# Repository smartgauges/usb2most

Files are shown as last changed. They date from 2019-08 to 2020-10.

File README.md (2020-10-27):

# usb2most
USB to MOST adapter to translate audio from a USB([UAC1](https://en.wikipedia.org/wiki/USB#Audio_streaming)) to MOST([Media Oriented Systems Transport](https://en.wikipedia.org/wiki/MOST_Bus)) bus

Interfaces:
- 8 audio channels(16bit/48kHz) over MOST bus
- 2 audio channels(16bit/48kHz) over USB
- 4 CAN for HS/HS" and MS/MS"
- 1 LIN for analogue watch
- 1 UART for CANBUS emulation

[More info](https://www.drive2.ru/l/524415370476389031/)

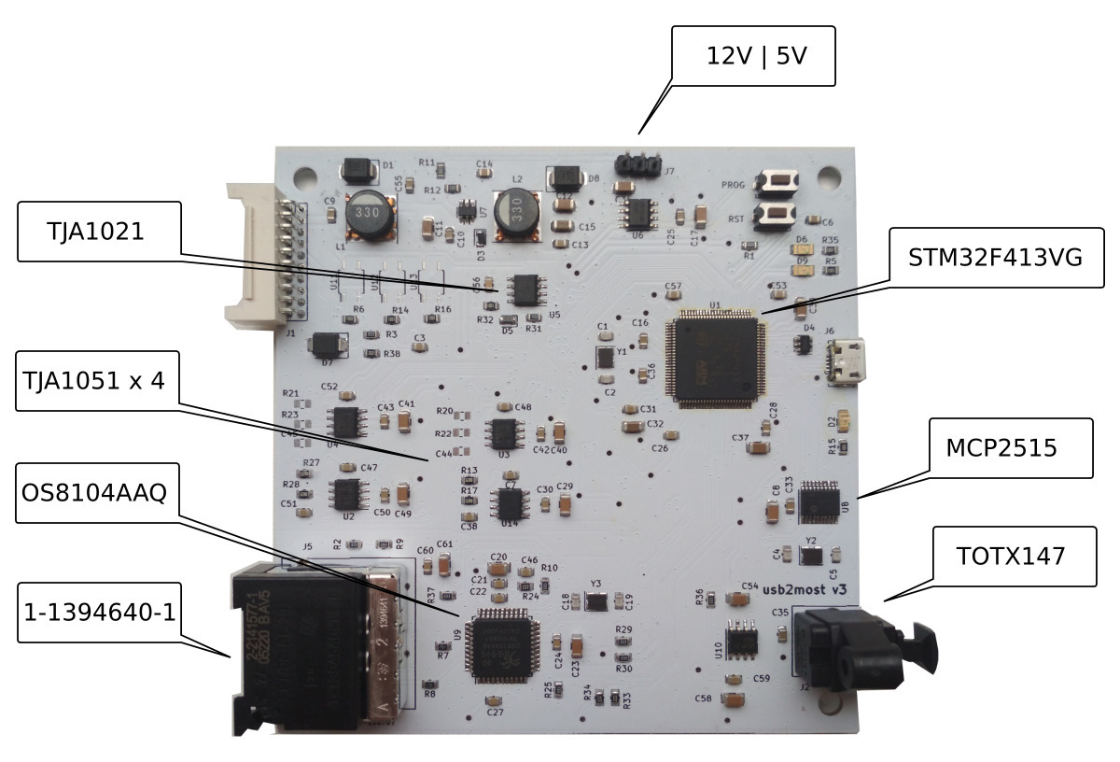
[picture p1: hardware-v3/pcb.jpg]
usb2most pcb


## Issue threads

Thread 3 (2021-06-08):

Any MOST25?

Denniscgaughan, 2021-06-08:
Would this inject audio over MOST25 network for nonspecific vehicles? Or exclusive to Land Rover MOST25? I plan for Audi with USB OTG android interface. i use auxiliary input currently.

Alexpux, 2021-06-08:
It's specific only for Freelander2

smartgauges, 2021-06-08:
Hello, in short, no, only some jlr models have support.
The firmware supports next MOST-devices :
- 8 and 12 channels amplifiers 6H52-18C808-XX, uses in lr freelander2 and jaguar xf
- radio unit 6G9N-18C815-XX , uses in lr freelander2 and jaguar xf
- 12 and 16 channels amplifiers XXXX-19C164-XX(AUD3-XX), uses in lr freelander2, some jaguar models, range rover IV, range rover evoque
- radio unit IAM2.1, uses in some jlr and volvo models

drug007, 2022-04-16:
Hello!
Is only the firmware specific to jlr models? And the hardware can be used in other vehicles by writing other firmware?

smartgauges, 2022-04-18:
> Hello! Is only the firmware specific to jlr models? And the hardware can be used in other vehicles by writing other firmware?

Hello, yes the firmware is jrl specific, but hardware can be used with any MOST25 devices

Denis-53, 2023-03-21:
hi is it possible to modify the software to emulate a audi most25 cd changer?

smartgauges, 2023-04-08:
> hi is it possible to modify the software to emulate a audi most25 cd changer?

Hello, without access to the car is not realistic

drug007, 2023-04-09:
I'm curious - Is it possible to make a remote access? Some form of a translator the MOST bus  into internet and back? And control information of course

Closed 2025-02-22.

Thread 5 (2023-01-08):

Resources for most

rhysmorgan134, 2023-01-08:
Hi,

I love your work you have done some really interesting stuff and written some really interesting documentation! One part i am wondering, how did you figure all of this out with the MOST bus? Information on it seems very well hidden out side of car manufacturers. I am working one a replacement touch screen for my jaguar, but the real tricky part is that it seems the old screen will have to be present for MOST bus control somwhere!

Thanks again! I've spent many hours reading your posts online

smartgauges, 2023-01-19:
Hello, thanks and sorry for the late reply.
In general terms, the specification for the MOST bus is open and can be found at [mostcooperation.com](https://www.mostcooperation.com/specifications/), also there you can find some specifications for different types of equipment (amplifier, HU, radio...)
[MOST_2V5_FBlock_Library](https://www.mostcooperation.com/fileadmin/content_filestorage/specifications/MOST_version_2V5/MOST_2V5_FBlock_Library.zip)
But almost always the vendor makes some vendor-specific features ((
What model is your jaguar?

rhysmorgan134, 2023-01-21:
Thankyou! I will take a good long read of that.

My jaguar is a 2008 XF, these contain the canbus-most gateway under the CD player. Currently I have relocated the screen and am making use of proxy device to overwrite the canbus messages from this for my needs.

However I would love to replace this entirely. I am awaiting some OS8104 chips to come and maybe have a play, being able to create a MOST sniffer similar to what we use for CAN would be the first goal!

rhysmorgan134, 2023-03-18:
Me again, I have been having a play with an os8104 chip and have managed to communicate with it and configure it. However when I put it in the MOST loop it seems to be creating some errors as the most loop keeps turning on and off my transceiver does power up and I have currently set it to all bypass.

would there be any chance of you sharing your start up registers and the values you are writing? I am also running and 18.432 MHz crystal, and looking through the manual this seems to point to the most frequency being 48Hz, so currently unsure as to why it seems to be faulting out the loop.

huge thanks again for what you shared on here, helped hugely in my experimentations so far!

rhysmorgan134, 2023-03-20:
Never mind, got the PCB and all works on there well, so issue must have be RX and TX legs being too long!

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

Closed 2023-03-20.

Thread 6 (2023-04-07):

Any pointers?

rhysmorgan134, 2023-04-07:
Hi again!

I have made quite a bit of progress so far, however there are a couple of bits that seem strange. For example, for the audio disk player function block the function for skipping track (0x453) always shows function not implemented (even though it responds with that function when i query it using 0x001)

Also volume doesn’t appear in any of the blocks or notifications so far. Are these something you have managed to figure out? If so how did you come across them?

Thanks in advance of any pointers!

smartgauges, 2023-04-08:
Hello, in my car(FL2) all the MOST-blocks are not implemented according to the MOST standards (.
Therefore, to implement support for any functional block, i first emulated this block on the usb2most board, and then replaced the native block with the usb2most board and investigated how the native head unit controls the emulated block.
In radio unit(6G9N-18C815-XX), i implemented the following blocks well: AUX, DSP, AM/FM tuner and support for the CD block is minimal - the search function has not been explored.

rhysmorgan134, 2023-04-08:
Thankyou! I’ll give that ago and see where I can get too. I haven’t had a chance to look into implementing the asynchronous messaging yet, it looks like you have achieved that from your schematic, was there much useful data on there?

I’ll be open sourcing my implementation so hopefully there may be some bits that you find useful when I get there!

Thanks, really appreciate it!

smartgauges, 2023-04-08:
In those blocks that I came across there were no asynchronous messages, only control messages.

rhysmorgan134, 2023-04-11:
I've managed to figure some messages out, such as skip forward/back and volume from the control panel. I went a slightly different route for the cd player, as I can't get the ring healthy by trying to emulate it.

I used the remote read message type, to directly read the receive message buffer from the cd player. Needs a bit of tidying up but seems to work well!

Closed 2025-02-22.

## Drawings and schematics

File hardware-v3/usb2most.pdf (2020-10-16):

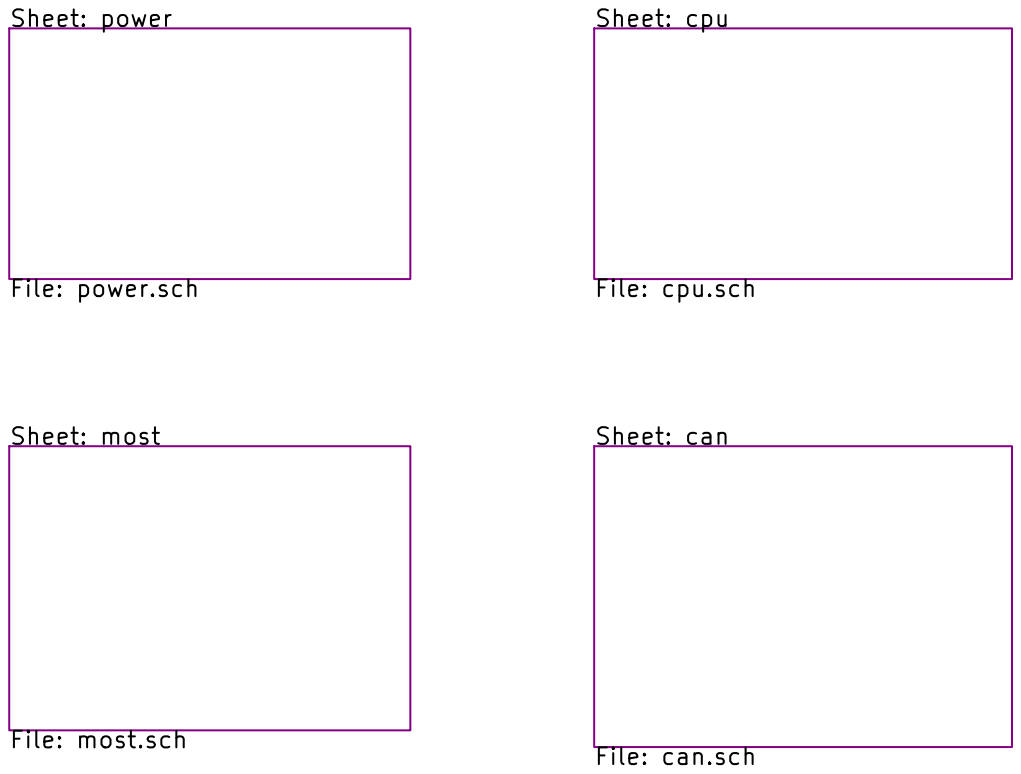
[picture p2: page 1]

Id: 1/5 Title: File: usb2most.sch Sheet: /

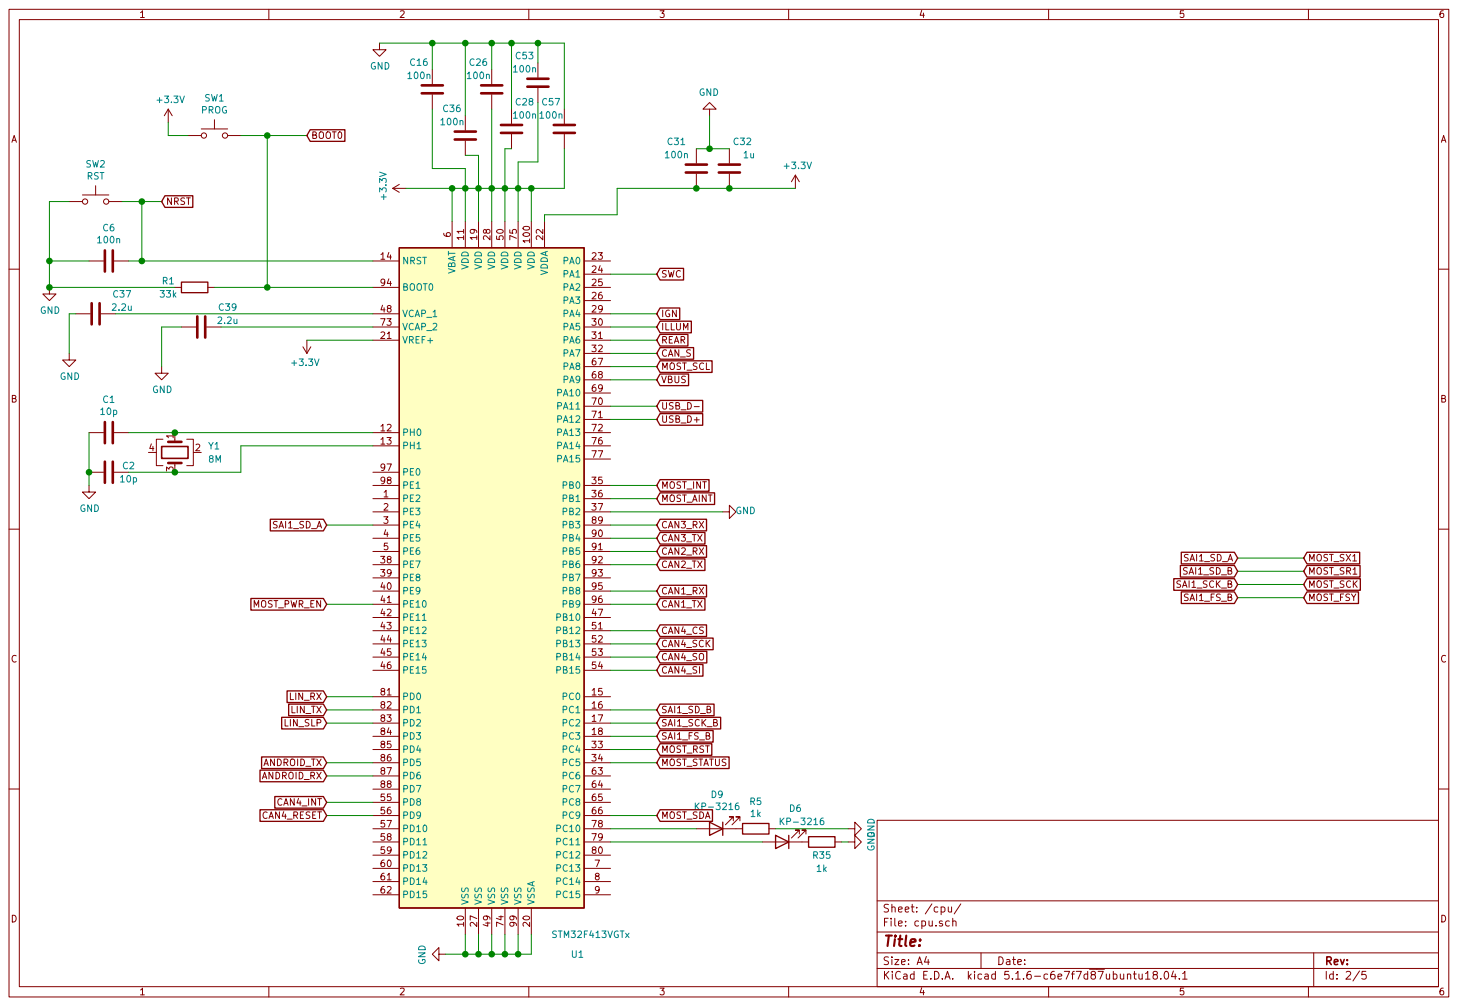
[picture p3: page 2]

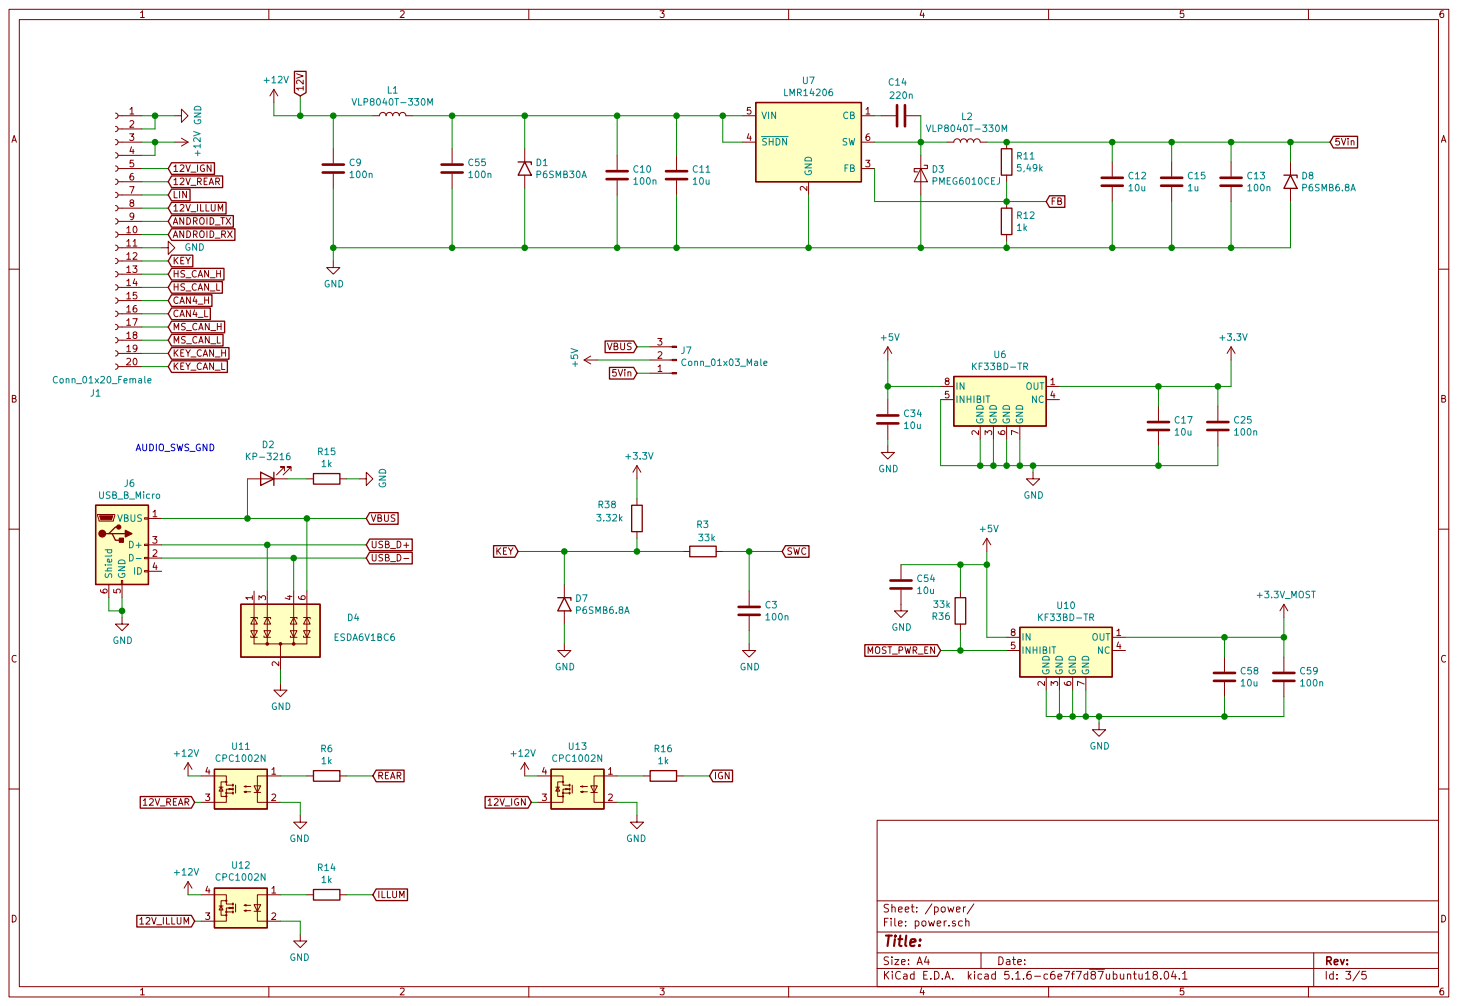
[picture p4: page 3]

2 FB 3 SHDN 4 VIN 5 SW 6 U7

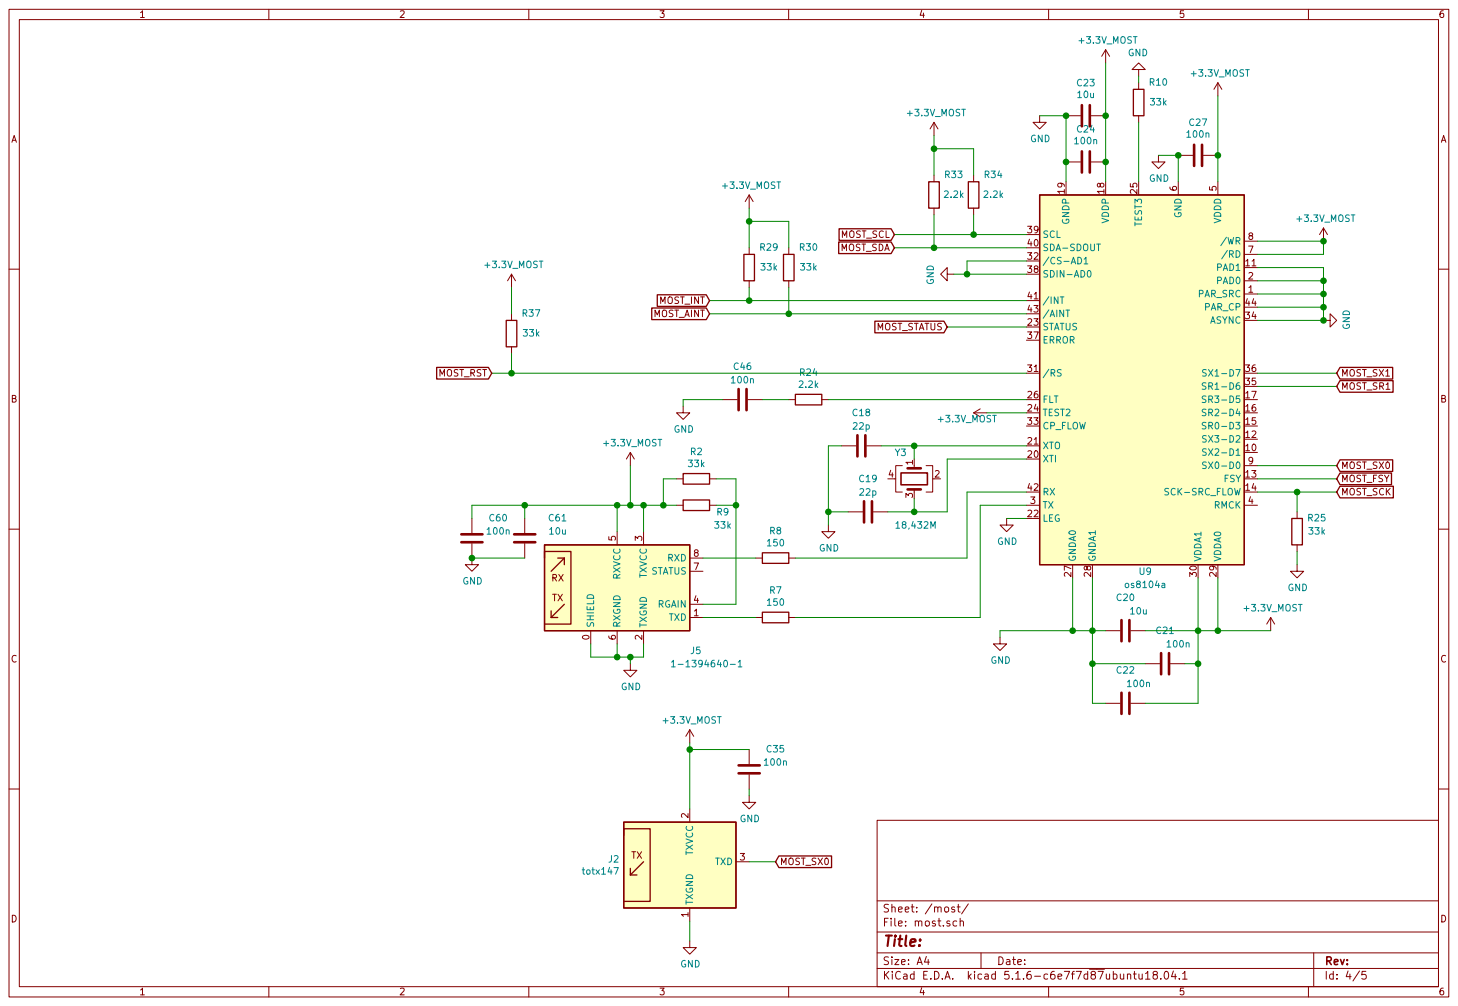
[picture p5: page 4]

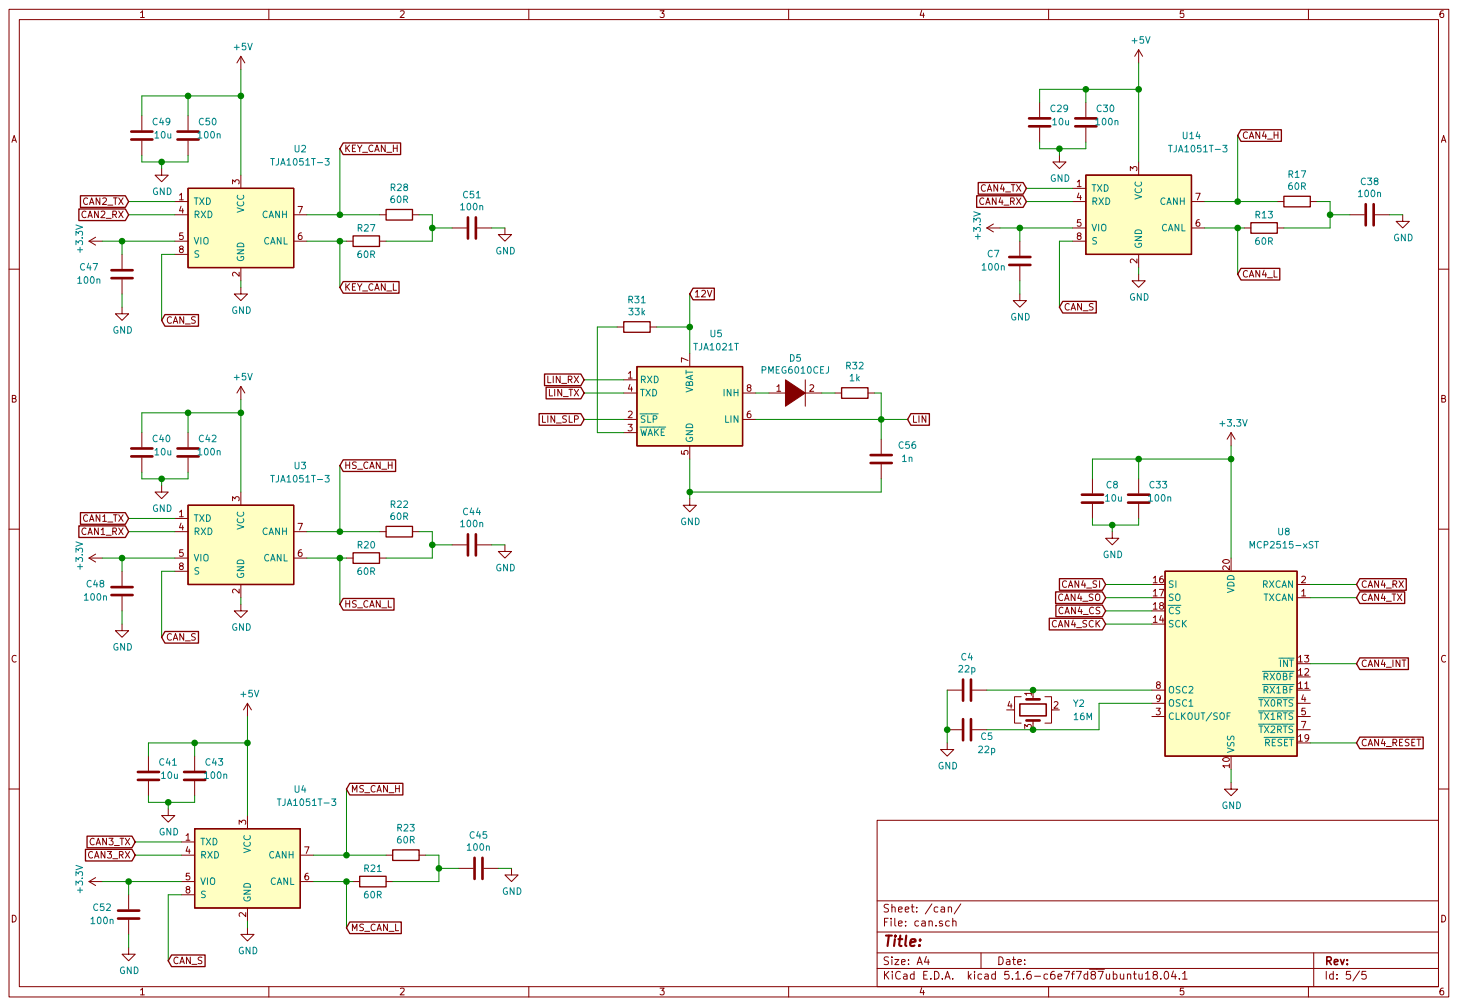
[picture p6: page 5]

Id: 5/5 Title: File: can.sch Sheet: /can/

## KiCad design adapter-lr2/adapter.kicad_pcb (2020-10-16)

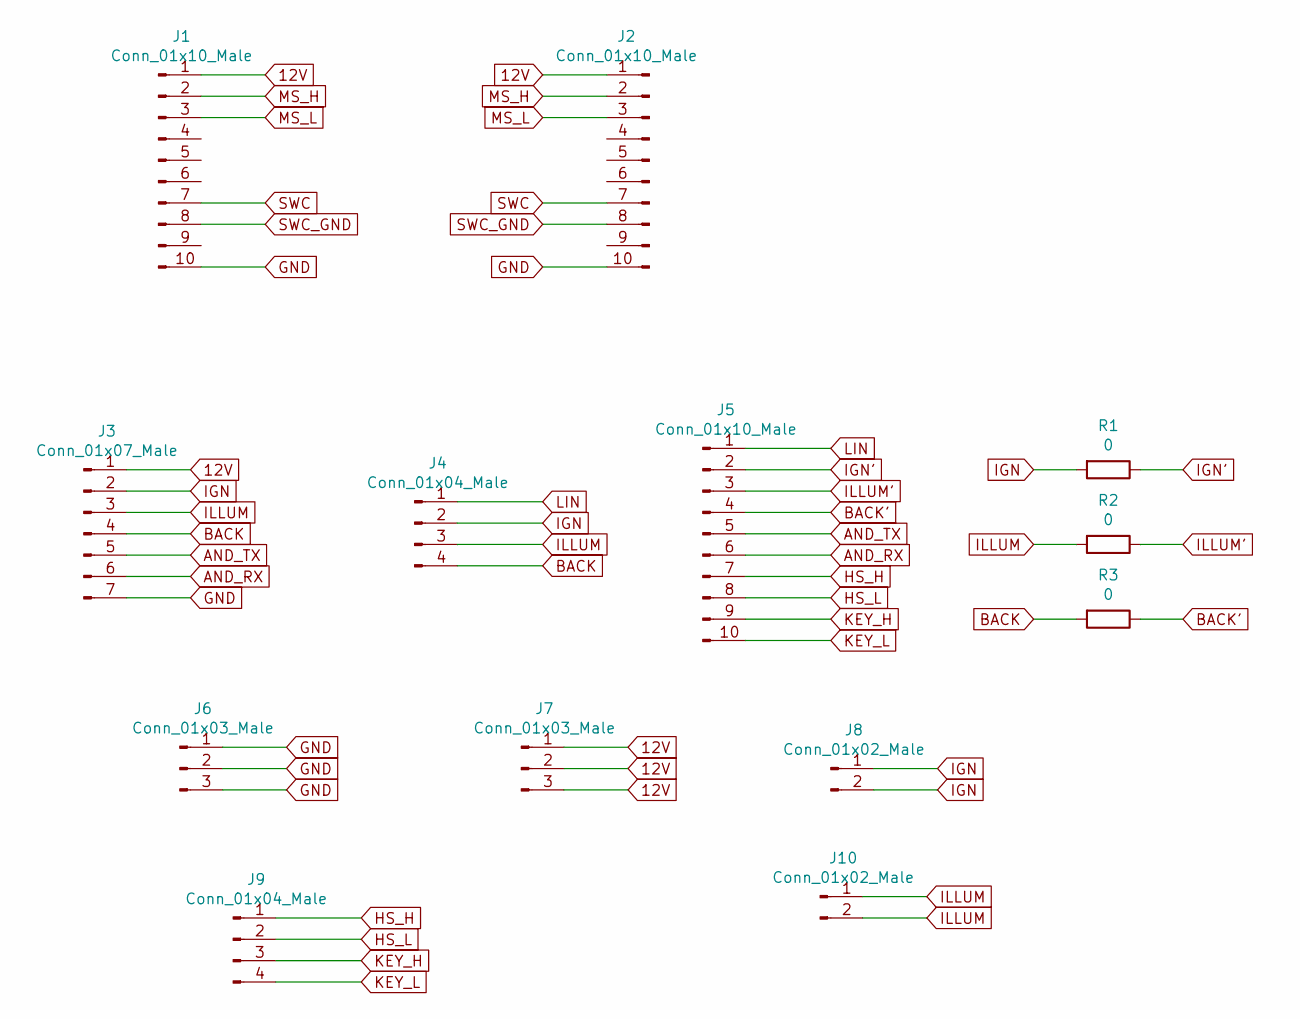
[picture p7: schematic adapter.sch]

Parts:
J1: Conn_01x10_Male; IL-AG5-10P-S3L2
J2, J5: Conn_01x10_Male; PinHeader_1x10_P2.54mm_Vertical
J3: Conn_01x07_Male; PinHeader_1x07_P2.54mm_Vertical
J4, J9: Conn_01x04_Male; PinHeader_1x04_P2.54mm_Vertical
J6, J7: Conn_01x03_Male; PinHeader_1x03_P2.54mm_Vertical
J8, J10: Conn_01x02_Male; PinHeader_1x02_P2.54mm_Vertical
R1, R2, R3: 0; R_0805_2012Metric

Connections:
12V: J1.1, J2.1, J3.1, J7.1, J7.2, J7.3
AND_RX: J3.6, J5.6
AND_TX: J3.5, J5.5
BACK: J3.4, J4.4, R3.2
BACK': J5.4, R3.1
GND: J1.10, J2.10, J3.7, J6.1, J6.2, J6.3
HS_H: J5.7, J9.1
HS_L: J5.8, J9.2
IGN: J3.2, J4.2, J8.1, J8.2, R1.2
IGN': J5.2, R1.1
ILLUM: J3.3, J4.3, J10.1, J10.2, R2.2
ILLUM': J5.3, R2.1
KEY_H: J5.9, J9.3
KEY_L: J5.10, J9.4
LIN: J4.1, J5.1
MS_H: J1.2, J2.2
MS_L: J1.3, J2.3
SWC: J1.7, J2.7
SWC_GND: J1.8, J2.8

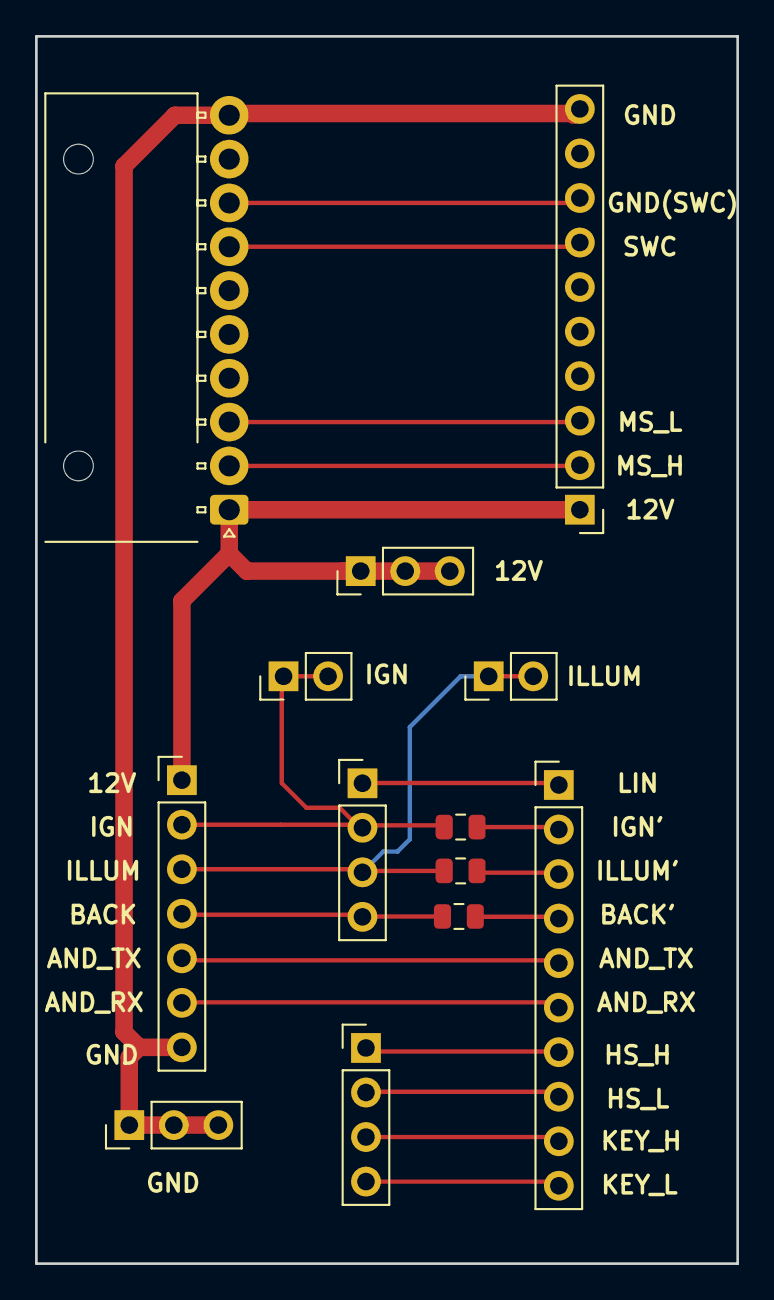
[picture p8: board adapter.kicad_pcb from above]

Board: 2 copper layers, 40.0 x 70.0 mm, 13 parts (0 on the bottom side), 19 nets.

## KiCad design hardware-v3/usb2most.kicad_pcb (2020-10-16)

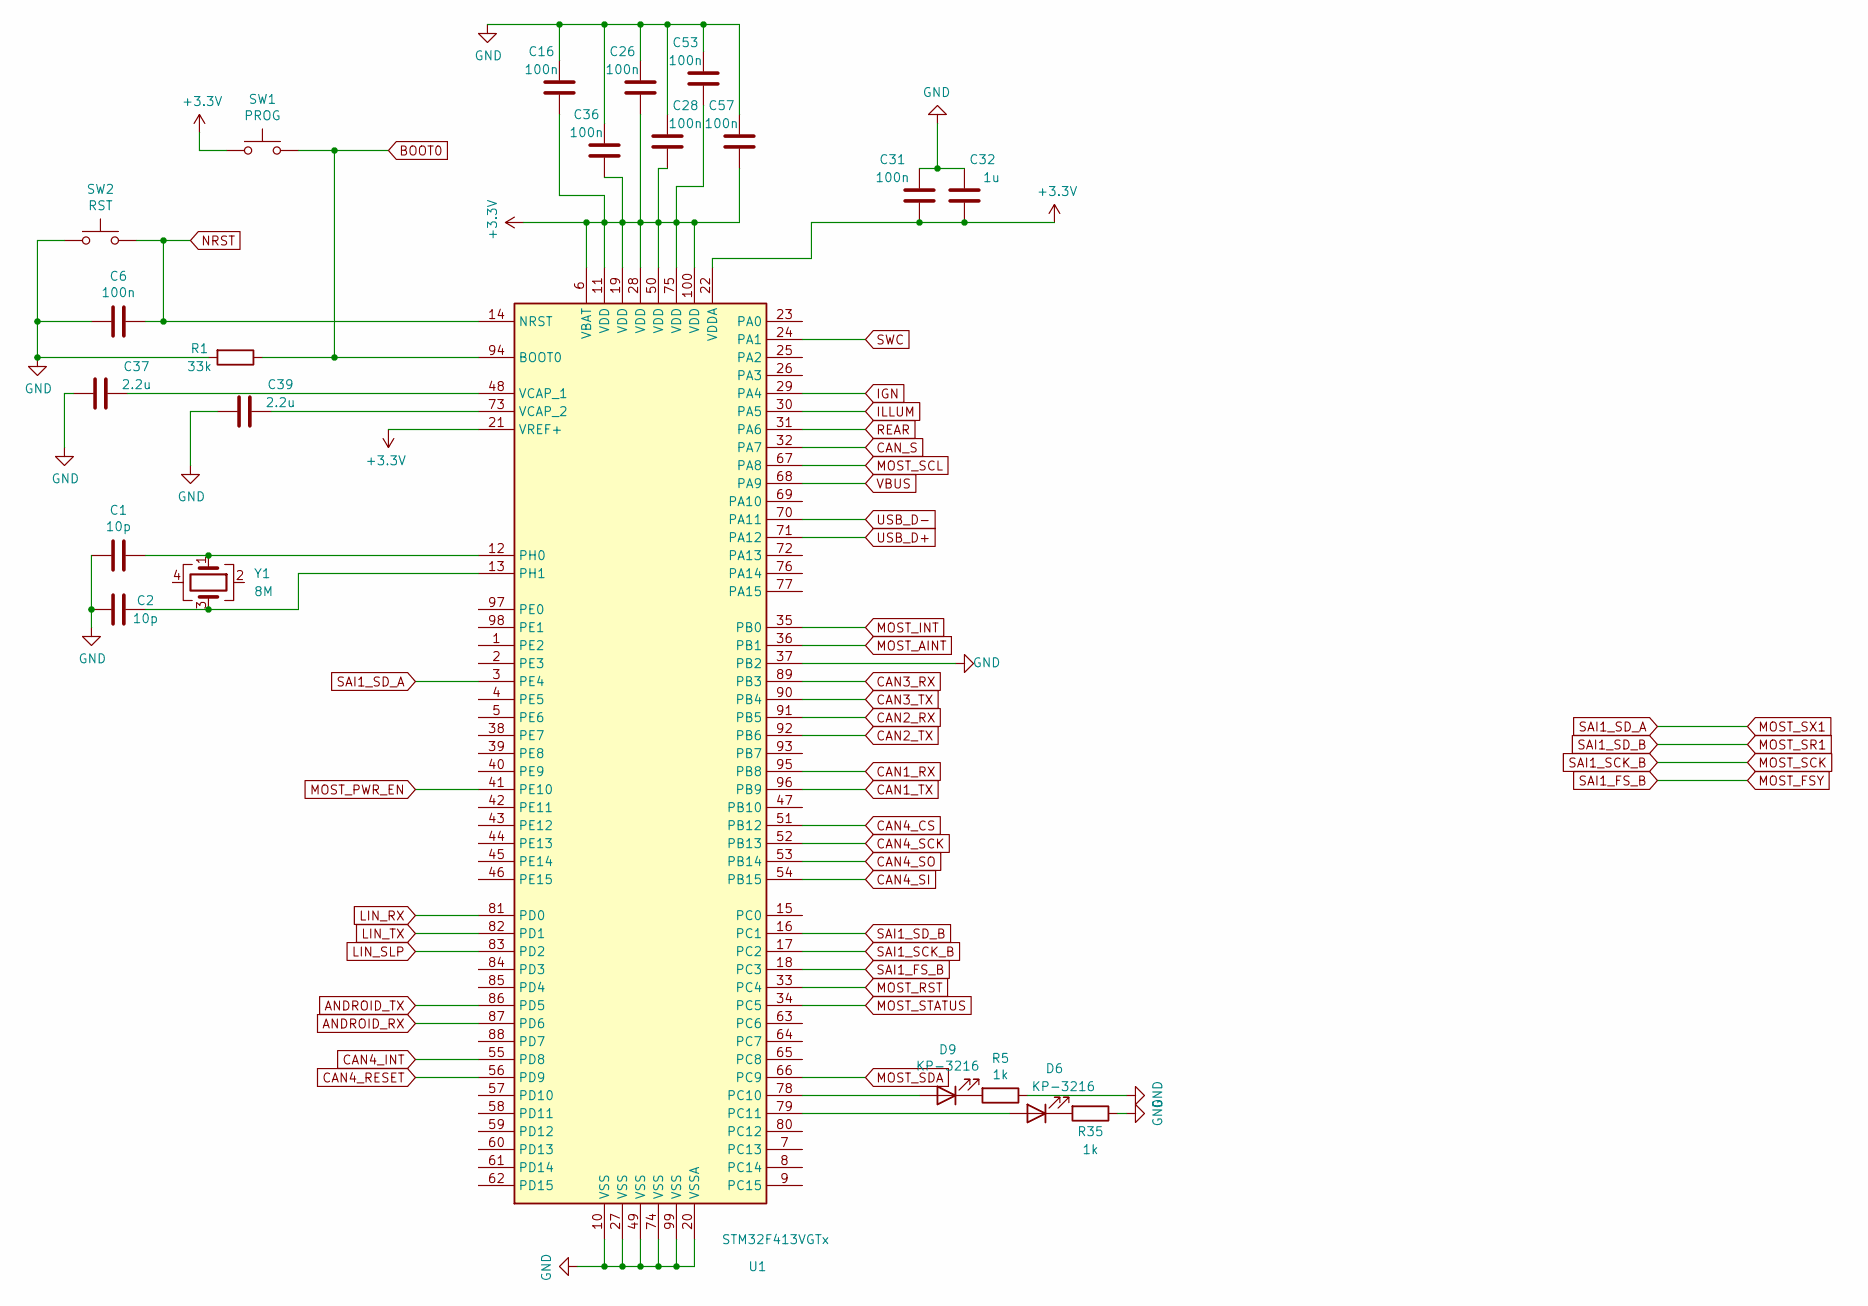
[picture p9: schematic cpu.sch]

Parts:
C1, C2: 10p; C_0805_2012Metric
C6, C16, C26, C28, C31, C36, C53, C57: 100n; C_0805_2012Metric
C32: 1u; C_1206_3216Metric
C37, C39: 2.2u; C_1206_3216Metric
D6, D9: KP-3216; R_1206_3216Metric
R1: 33k; R_0805_2012Metric
R5, R35: 1k; R_0805_2012Metric
SW1: PROG; SW_SPST_EVQPE1
SW2: RST; SW_SPST_EVQPE1
U1: STM32F413VGTx; LQFP-100_14x14mm_P0.5mm
Y1: 8M; Crystal_SMD_3225-4Pin_3.2x2.5mm

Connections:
+3V3: C16.1, C26.1, C28.1, C31.1, C32.1, C36.1, C53.1, C57.1, SW1.1, U1.6 (VBAT), U1.11 (VDD), U1.19 (VDD), U1.21 (VREF+), U1.22 (VDDA), U1.28 (VDD), U1.50 (VDD), U1.75 (VDD), U1.100 (VDD); also elsewhere on the board
ANDROID_RX: U1.87 (PD6); also elsewhere on the board
ANDROID_TX: U1.86 (PD5); also elsewhere on the board
BOOT0: R1.1, SW1.2, U1.94 (BOOT0)
CAN1_RX: U1.95 (PB8); also elsewhere on the board
CAN1_TX: U1.96 (PB9); also elsewhere on the board
CAN2_RX: U1.91 (PB5); also elsewhere on the board
CAN2_TX: U1.92 (PB6); also elsewhere on the board
CAN3_RX: U1.89 (PB3); also elsewhere on the board
CAN3_TX: U1.90 (PB4); also elsewhere on the board
CAN4_CS: U1.51 (PB12); also elsewhere on the board
CAN4_INT: U1.55 (PD8); also elsewhere on the board
CAN4_RESET: U1.56 (PD9); also elsewhere on the board
CAN4_SCK: U1.52 (PB13); also elsewhere on the board
CAN4_SI: U1.54 (PB15); also elsewhere on the board
CAN4_SO: U1.53 (PB14); also elsewhere on the board
CAN_S: U1.32 (PA7); also elsewhere on the board
GND: C1.2, C2.2, C6.2, C16.2, C26.2, C28.2, C31.2, C32.2, C36.2, C37.2, C39.2, C53.2, C57.2, R1.2, R5.1, R35.1, SW2.1, U1.10 (VSS), U1.20 (VSSA), U1.27 (VSS), U1.37 (PB2), U1.49 (VSS), U1.74 (VSS), U1.99 (VSS); also elsewhere on the board
IGN: U1.29 (PA4); also elsewhere on the board
ILLUM: U1.30 (PA5); also elsewhere on the board
LIN_RX: U1.81 (PD0); also elsewhere on the board
LIN_SLP: U1.83 (PD2); also elsewhere on the board
LIN_TX: U1.82 (PD1); also elsewhere on the board
MOST_AINT: U1.36 (PB1); also elsewhere on the board
MOST_FSY: U1.18 (PC3); also elsewhere on the board
MOST_INT: U1.35 (PB0); also elsewhere on the board
MOST_PWR_EN: U1.41 (PE10); also elsewhere on the board
MOST_RST: U1.33 (PC4); also elsewhere on the board
MOST_SCK: U1.17 (PC2); also elsewhere on the board
MOST_SCL: U1.67 (PA8); also elsewhere on the board
MOST_SDA: U1.66 (PC9); also elsewhere on the board
MOST_SR1: U1.16 (PC1); also elsewhere on the board
MOST_STATUS: U1.34 (PC5); also elsewhere on the board
MOST_SX1: U1.3 (PE4); also elsewhere on the board
NRST: C6.1, SW2.2, U1.14 (NRST)
unnamed: C1.1, U1.12 (PH0), Y1.1
unnamed: C2.1, U1.13 (PH1), Y1.3
unnamed: C37.1, U1.48 (VCAP_1)
unnamed: C39.1, U1.73 (VCAP_2)
unnamed: D6.1 (K), R35.2
unnamed: D6.2 (A), U1.79 (PC11)
unnamed: D9.1 (K), R5.2
unnamed: D9.2 (A), U1.78 (PC10)
REAR: U1.31 (PA6); also elsewhere on the board
SWC: U1.24 (PA1); also elsewhere on the board
USB_D+: U1.71 (PA12); also elsewhere on the board
USB_D-: U1.70 (PA11); also elsewhere on the board
VBUS: U1.68 (PA9); also elsewhere on the board

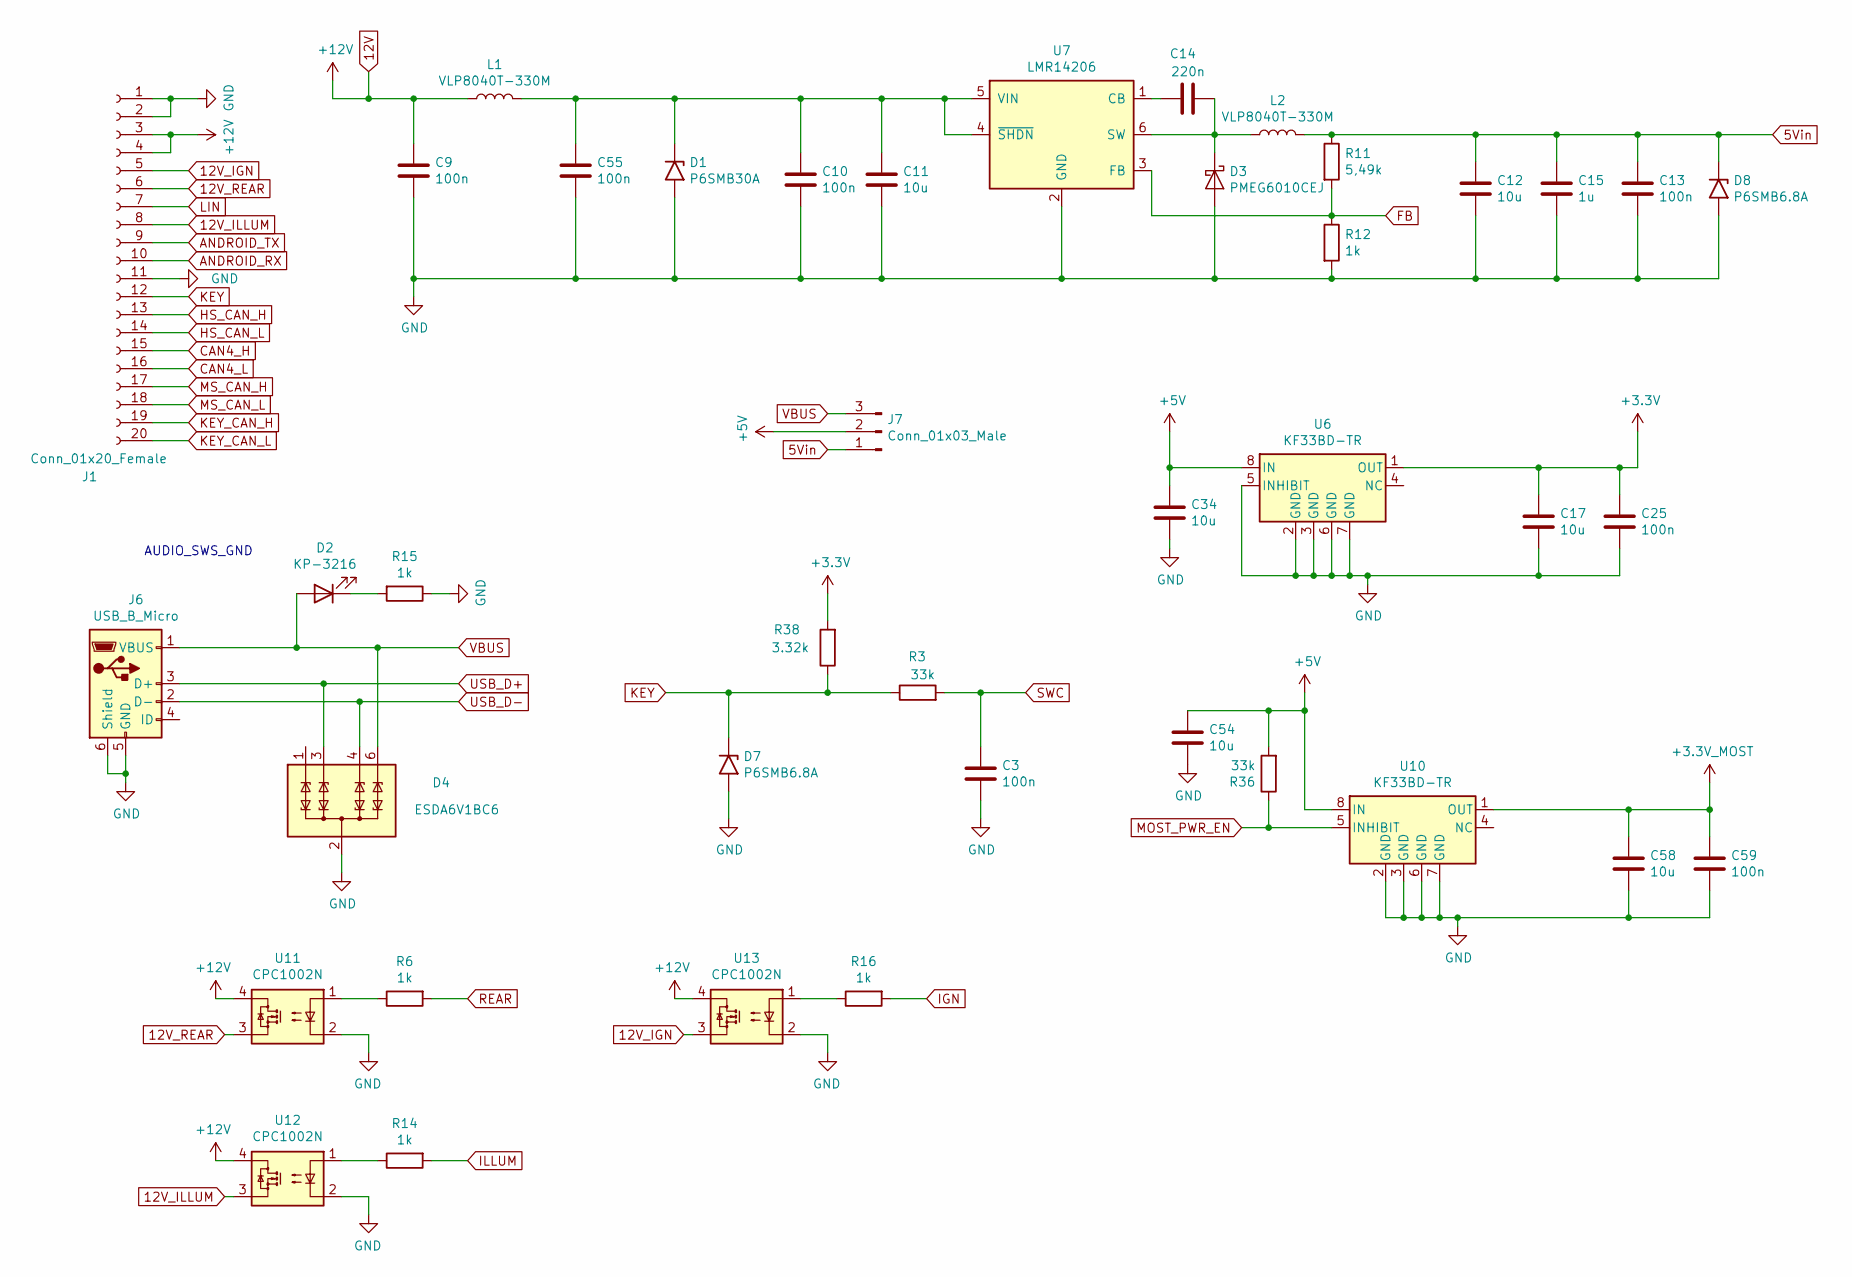
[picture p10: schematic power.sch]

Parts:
C3, C9, C10, C13, C25, C55, C59: 100n; C_0805_2012Metric
C11, C12, C17, C34, C54, C58: 10u; C_1206_3216Metric
C14: 220n; C_0805_2012Metric
C15: 1u; C_1206_3216Metric
D1: P6SMB30A; D_SMB
D2: KP-3216; R_1206_3216Metric
D3: PMEG6010CEJ; D_0805_2012Metric
D4: ESDA6V1BC6; SOT-23-6
D7, D8: P6SMB6.8A; D_SMB
J1: Conn_01x20_Female; PinHeader_2x10_P2.00mm_Vertical
J6: USB_B_Micro; USB_Micro-B_Molex-105017-0001
J7: Conn_01x03_Male; PinSocket_1x03_P2.54mm_Vertical
L1, L2: VLP8040T-330M; L_TDK_VLP8040
R3, R36: 33k; R_0805_2012Metric
R6, R12, R14, R15, R16: 1k; R_0805_2012Metric
R11: 5,49k; R_0805_2012Metric
R38: 3.32k; R_0805_2012Metric
U6, U10: KF33BD-TR; SO-8_3.9x4.9mm_P1.27mm
U7: LMR14206; SOT-23-6_Handsoldering
U11, U12, U13: CPC1002N; SOP-4_3.8x4.1mm_P2.54mm

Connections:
5Vin: C12.1, C13.1, C15.1, D8.1 (A1), J7.1, L2.2, R11.1
12V: C9.1, J1.3, J1.4, L1.1, U11.4, U12.4, U13.4; also elsewhere on the board
12V_IGN: J1.5, U13.3
12V_ILLUM: J1.8, U12.3
12V_REAR: J1.6, U11.3
+3.3_MOST: C58.1, C59.1, U10.1 (OUT); also elsewhere on the board
+3V3: C17.1, C25.1, R38.2, U6.1 (OUT); also elsewhere on the board
+5V: C34.1, C54.1, J7.2, R36.2, U6.8 (IN), U10.8 (IN); also elsewhere on the board
ANDROID_RX: J1.10; also elsewhere on the board
ANDROID_TX: J1.9; also elsewhere on the board
CAN4_H: J1.15; also elsewhere on the board
CAN4_L: J1.16; also elsewhere on the board
FB: R11.2, R12.1, U7.3 (FB)
GND: C3.2, C9.2, C10.2, C11.2, C12.2, C13.2, C15.2, C17.2, C25.2, C34.2, C54.2, C55.2, C58.2, C59.2, D1.2 (A2), D3.2 (A), D4.2 (COM), D4.5 (COM), D7.2 (A2), D8.2 (A2), J1.1, J1.2, J1.11, J6.5 (GND), J6.6 (Shield), R12.2, R15.1, U6.2 (GND), U6.3 (GND), U6.5 (INHIBIT), U6.6 (GND), U6.7 (GND), U7.2 (GND), U10.2 (GND), U10.3 (GND), U10.6 (GND), U10.7 (GND), U11.2, U12.2, U13.2; also elsewhere on the board
HS_CAN_H: J1.13; also elsewhere on the board
HS_CAN_L: J1.14; also elsewhere on the board
IGN: R16.2; also elsewhere on the board
ILLUM: R14.2; also elsewhere on the board
KEY: D7.1 (A1), J1.12, R3.1, R38.1
KEY_CAN_H: J1.19; also elsewhere on the board
KEY_CAN_L: J1.20; also elsewhere on the board
LIN: J1.7; also elsewhere on the board
MOST_PWR_EN: R36.1, U10.5 (INHIBIT); also elsewhere on the board
MS_CAN_H: J1.17; also elsewhere on the board
MS_CAN_L: J1.18; also elsewhere on the board
unnamed: C10.1, C11.1, C55.1, D1.1 (A1), L1.2, U7.4 (~SHDN), U7.5 (VIN)
unnamed: C14.1, U7.1 (CB)
unnamed: C14.2, D3.1 (K), L2.1, U7.6 (SW)
unnamed: D2.1 (K), R15.2
unnamed: R6.1, U11.1
unnamed: R14.1, U12.1
unnamed: R16.1, U13.1
REAR: R6.2; also elsewhere on the board
SWC: C3.1, R3.2; also elsewhere on the board
USB_D+: D4.3 (TVS2), J6.3 (D+); also elsewhere on the board
USB_D-: D4.4 (TVS3), J6.2 (D-); also elsewhere on the board
VBUS: D2.2 (A), D4.6 (TVS4), J6.1 (VBUS), J7.3; also elsewhere on the board

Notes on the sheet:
AUDIO_SWS_GND

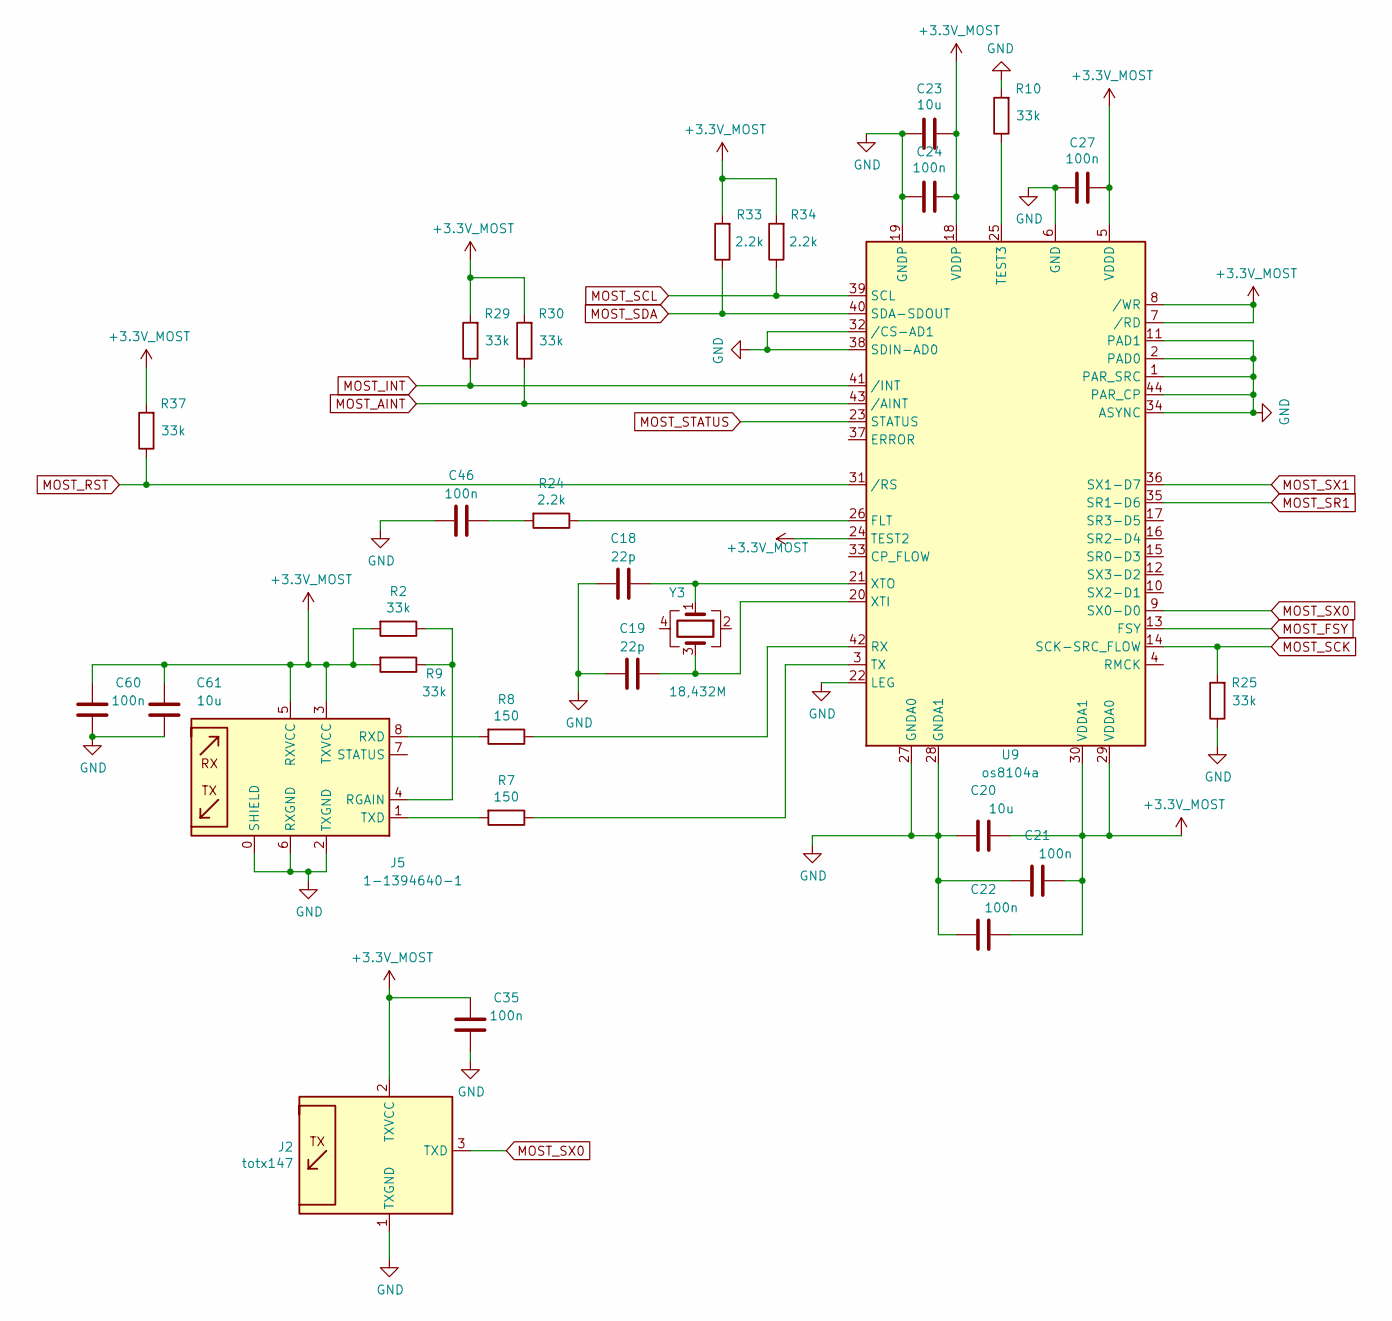
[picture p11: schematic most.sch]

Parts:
C18, C19: 22p; C_0805_2012Metric
C20, C23, C61: 10u; C_1206_3216Metric
C21, C22, C24, C27, C35, C46, C60: 100n; C_0805_2012Metric
J2: totx147; TOTX147
J5: 1-1394640-1; TYCO_1_1394640_1
R2, R9, R10, R25, R29, R30, R37: 33k; R_0805_2012Metric
R7, R8: 150; R_0805_2012Metric
R24, R33, R34: 2.2k; R_0805_2012Metric
U9: os8104a; LQFP-44_10x10mm_P0.8mm
Y3: 18,432M; Crystal_SMD_3225-4Pin_3.2x2.5mm

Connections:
+3.3_MOST: C20.1, C21.1, C22.1, C23.1, C24.1, C27.1, C35.2, C60.2, C61.2, J2.2 (TXVCC), J5.3 (TXVCC), J5.5 (RXVCC), R2.2, R9.2, R29.2, R30.2, R33.2, R34.2, R37.2, U9.5 (VDDD), U9.7 (/RD), U9.8 (/WR), U9.18 (VDDP), U9.24 (TEST2), U9.29 (VDDA0), U9.30 (VDDA1); also elsewhere on the board
GND: C18.2, C19.2, C20.2, C21.2, C22.2, C23.2, C24.2, C27.2, C35.1, C46.2, C60.1, C61.1, J2.1 (TXGND), J5.0 (SHIELD), J5.2 (TXGND), J5.6 (RXGND), R10.2, R25.1, U9.1 (PAR_SRC), U9.2 (PAD0), U9.6 (GND), U9.11 (PAD1), U9.19 (GNDP), U9.22 (LEG), U9.27 (GNDA0), U9.28 (GNDA1), U9.32 (/CS-AD1), U9.34 (ASYNC), U9.38 (SDIN-AD0), U9.44 (PAR_CP); also elsewhere on the board
MOST_AINT: R30.1, U9.43 (/AINT); also elsewhere on the board
MOST_FSY: U9.13 (FSY); also elsewhere on the board
MOST_INT: R29.1, U9.41 (/INT); also elsewhere on the board
MOST_RST: R37.1, U9.31 (/RS); also elsewhere on the board
MOST_SCK: R25.2, U9.14 (SCK-SRC_FLOW); also elsewhere on the board
MOST_SCL: R34.1, U9.39 (SCL); also elsewhere on the board
MOST_SDA: R33.1, U9.40 (SDA-SDOUT); also elsewhere on the board
MOST_SR1: U9.35 (SR1-D6); also elsewhere on the board
MOST_STATUS: U9.23 (STATUS); also elsewhere on the board
MOST_SX0: J2.3 (TXD), U9.9 (SX0-D0)
MOST_SX1: U9.36 (SX1-D7); also elsewhere on the board
unnamed: C18.1, U9.21 (XTO), Y3.1
unnamed: C19.1, U9.20 (XTI), Y3.3
unnamed: C46.1, R24.2
unnamed: J5.1 (TXD), R7.2
unnamed: J5.4 (RGAIN), R2.1, R9.1
unnamed: J5.8 (RXD), R8.2
unnamed: R7.1, U9.3 (TX)
unnamed: R8.1, U9.42 (RX)
unnamed: R10.1, U9.25 (TEST3)
unnamed: R24.1, U9.26 (FLT)

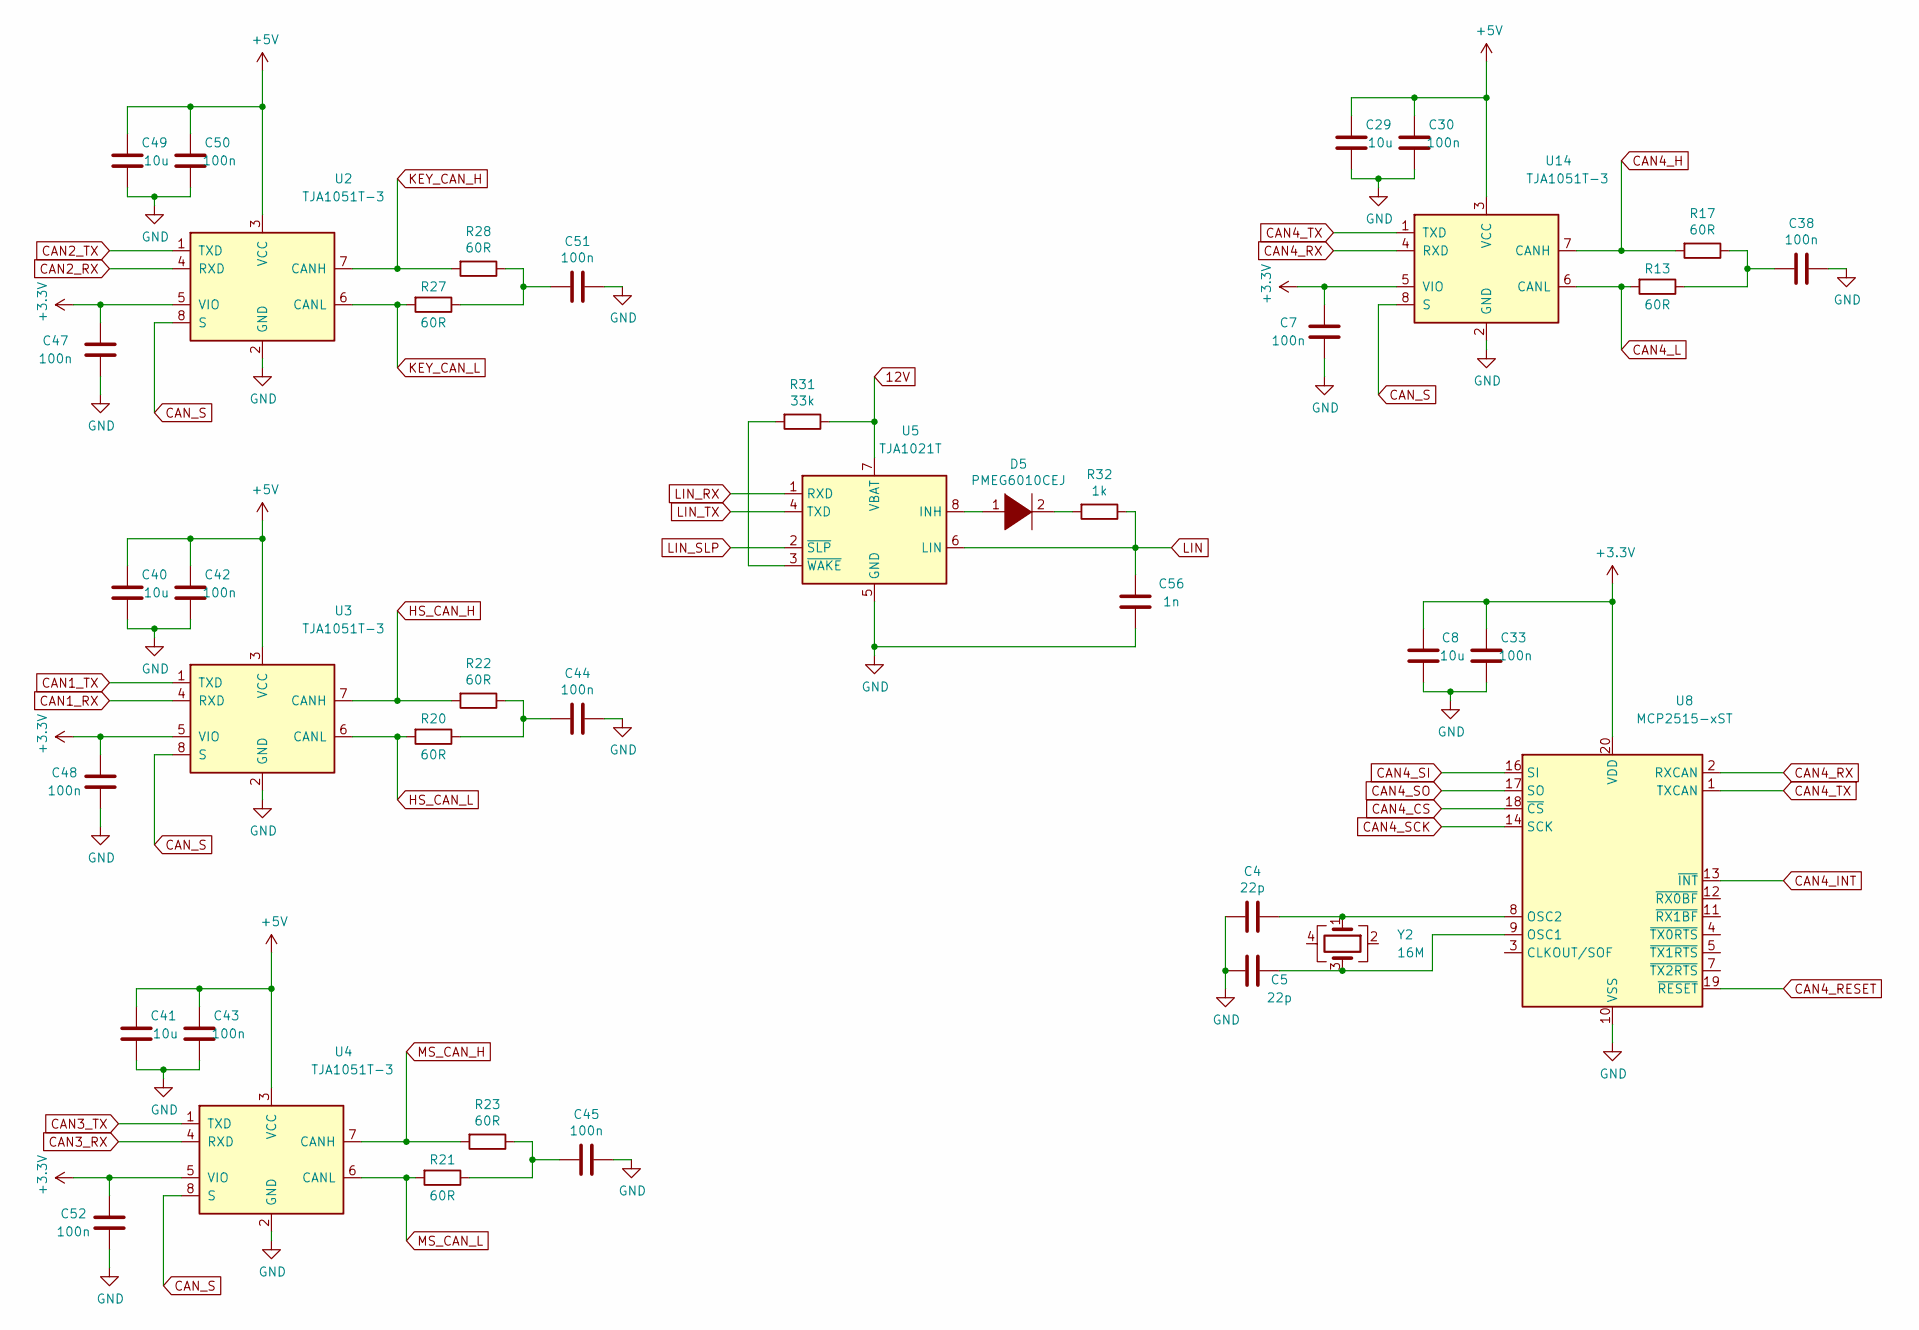
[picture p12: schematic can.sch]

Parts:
C4, C5: 22p; C_0805_2012Metric
C7, C30, C33, C38, C42, C43, C44, C45, C47, C48, C50, C51, C52: 100n; C_0805_2012Metric
C8, C29, C40, C41, C49: 10u; C_1206_3216Metric
C56: 1n; C_0805_2012Metric
D5: PMEG6010CEJ; D_0805_2012Metric
R13, R17, R20, R21, R22, R23, R27, R28: 60R; R_0805_2012Metric
R31: 33k; R_0805_2012Metric
R32: 1k; R_0805_2012Metric
U2, U3, U4, U14: TJA1051T-3; SOIC-8_3.9x4.9mm_P1.27mm
U5: TJA1021T; SOIC-8_3.9x4.9mm_P1.27mm
U8: MCP2515-xST; TSSOP-20_4.4x6.5mm_P0.65mm
Y2: 16M; Crystal_SMD_3225-4Pin_3.2x2.5mm

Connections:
12V: R31.1, U5.7 (VBAT); also elsewhere on the board
+3V3: C7.2, C8.2, C33.2, C47.2, C48.2, C52.2, U2.5 (VIO), U3.5 (VIO), U4.5 (VIO), U8.20 (VDD), U14.5 (VIO); also elsewhere on the board
+5V: C29.2, C30.2, C40.2, C41.2, C42.2, C43.2, C49.2, C50.2, U2.3 (VCC), U3.3 (VCC), U4.3 (VCC), U14.3 (VCC); also elsewhere on the board
CAN1_RX: U3.4 (RXD); also elsewhere on the board
CAN1_TX: U3.1 (TXD); also elsewhere on the board
CAN2_RX: U2.4 (RXD); also elsewhere on the board
CAN2_TX: U2.1 (TXD); also elsewhere on the board
CAN3_RX: U4.4 (RXD); also elsewhere on the board
CAN3_TX: U4.1 (TXD); also elsewhere on the board
CAN4_CS: U8.18 (~CS); also elsewhere on the board
CAN4_H: R17.2, U14.7 (CANH); also elsewhere on the board
CAN4_INT: U8.13 (~INT); also elsewhere on the board
CAN4_L: R13.2, U14.6 (CANL); also elsewhere on the board
CAN4_RESET: U8.19 (~RESET); also elsewhere on the board
CAN4_RX: U8.2 (RXCAN), U14.4 (RXD)
CAN4_SCK: U8.14 (SCK); also elsewhere on the board
CAN4_SI: U8.16 (SI); also elsewhere on the board
CAN4_SO: U8.17 (SO); also elsewhere on the board
CAN4_TX: U8.1 (TXCAN), U14.1 (TXD)
CAN_S: U2.8 (S), U3.8 (S), U4.8 (S), U14.8 (S); also elsewhere on the board
GND: C4.2, C5.2, C7.1, C8.1, C29.1, C30.1, C33.1, C38.1, C40.1, C41.1, C42.1, C43.1, C44.1, C45.1, C47.1, C48.1, C49.1, C50.1, C51.1, C52.1, C56.1, U2.2 (GND), U3.2 (GND), U4.2 (GND), U5.5 (GND), U8.10 (VSS), U14.2 (GND); also elsewhere on the board
HS_CAN_H: R22.2, U3.7 (CANH); also elsewhere on the board
HS_CAN_L: R20.2, U3.6 (CANL); also elsewhere on the board
KEY_CAN_H: R28.2, U2.7 (CANH); also elsewhere on the board
KEY_CAN_L: R27.2, U2.6 (CANL); also elsewhere on the board
LIN: C56.2, R32.1, U5.6 (LIN); also elsewhere on the board
LIN_RX: U5.1 (RXD); also elsewhere on the board
LIN_SLP: U5.2 (~SLP~); also elsewhere on the board
LIN_TX: U5.4 (TXD); also elsewhere on the board
MS_CAN_H: R23.2, U4.7 (CANH); also elsewhere on the board
MS_CAN_L: R21.2, U4.6 (CANL); also elsewhere on the board
unnamed: C4.1, U8.8 (OSC2), Y2.1
unnamed: C5.1, U8.9 (OSC1), Y2.3
unnamed: C38.2, R13.1, R17.1
unnamed: C44.2, R20.1, R22.1
unnamed: C45.2, R21.1, R23.1
unnamed: C51.2, R27.1, R28.1
unnamed: D5.1 (K), U5.8 (INH)
unnamed: D5.2 (A), R32.2
unnamed: R31.2, U5.3 (~WAKE~)

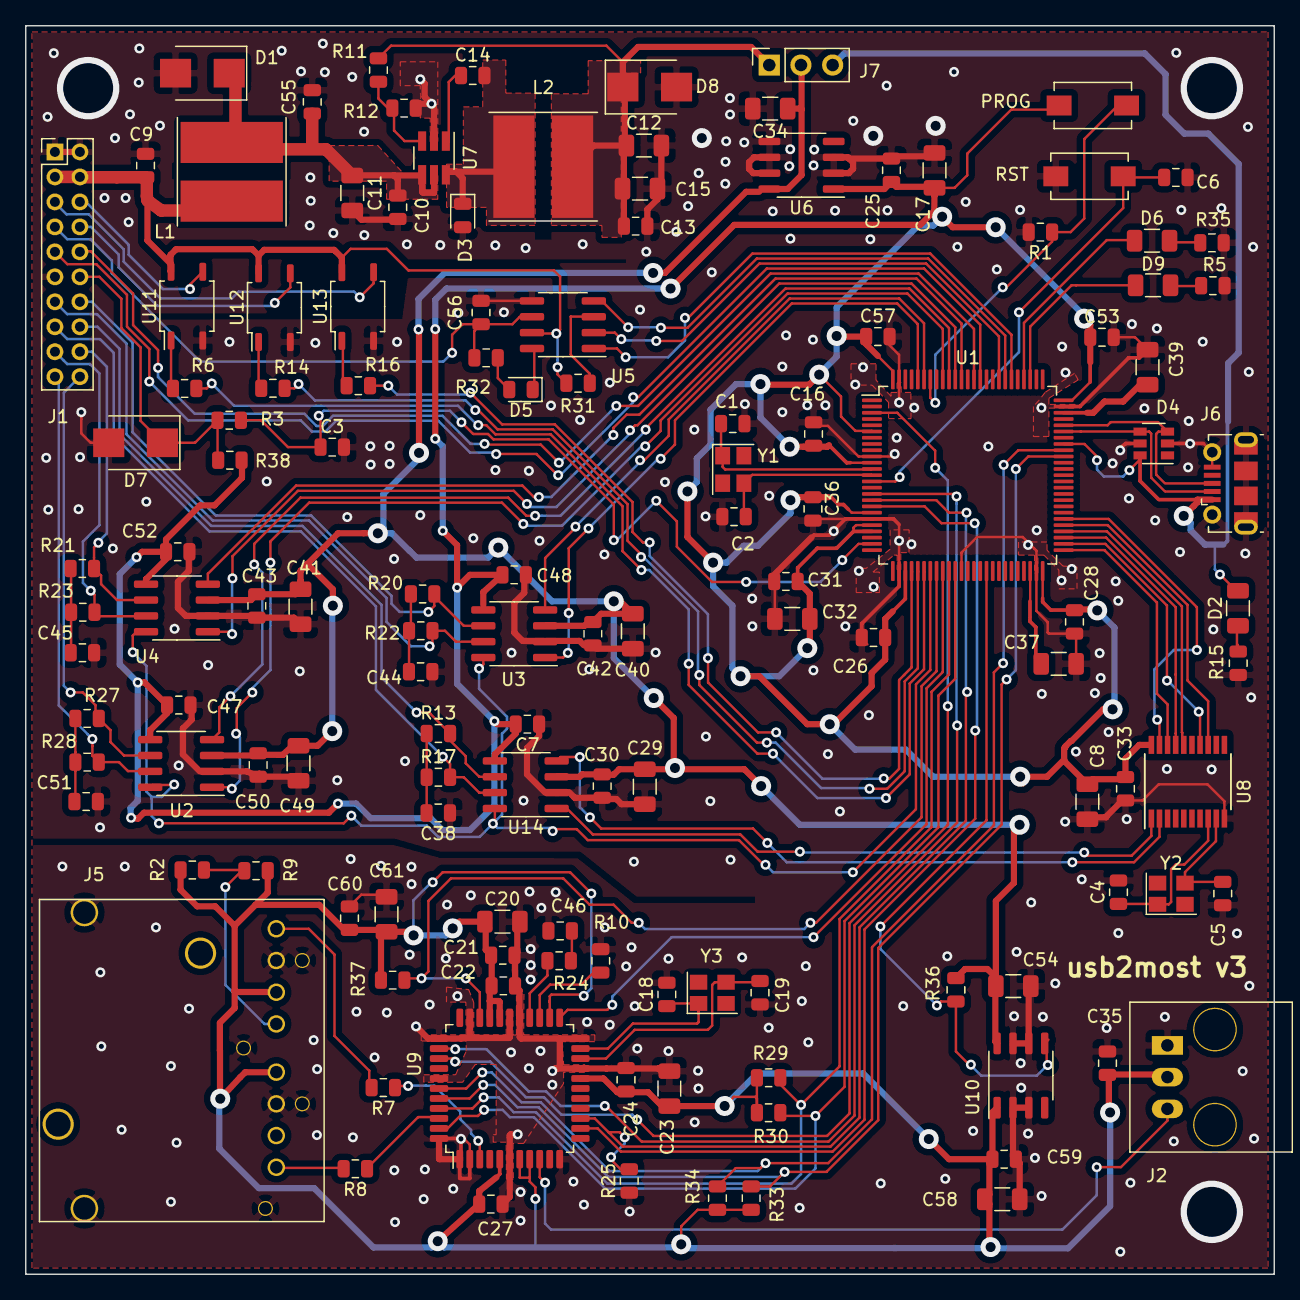
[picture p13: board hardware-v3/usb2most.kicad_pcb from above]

Board: 2 copper layers, 100.0 x 100.0 mm, 130 parts (0 on the bottom side), 95 nets.

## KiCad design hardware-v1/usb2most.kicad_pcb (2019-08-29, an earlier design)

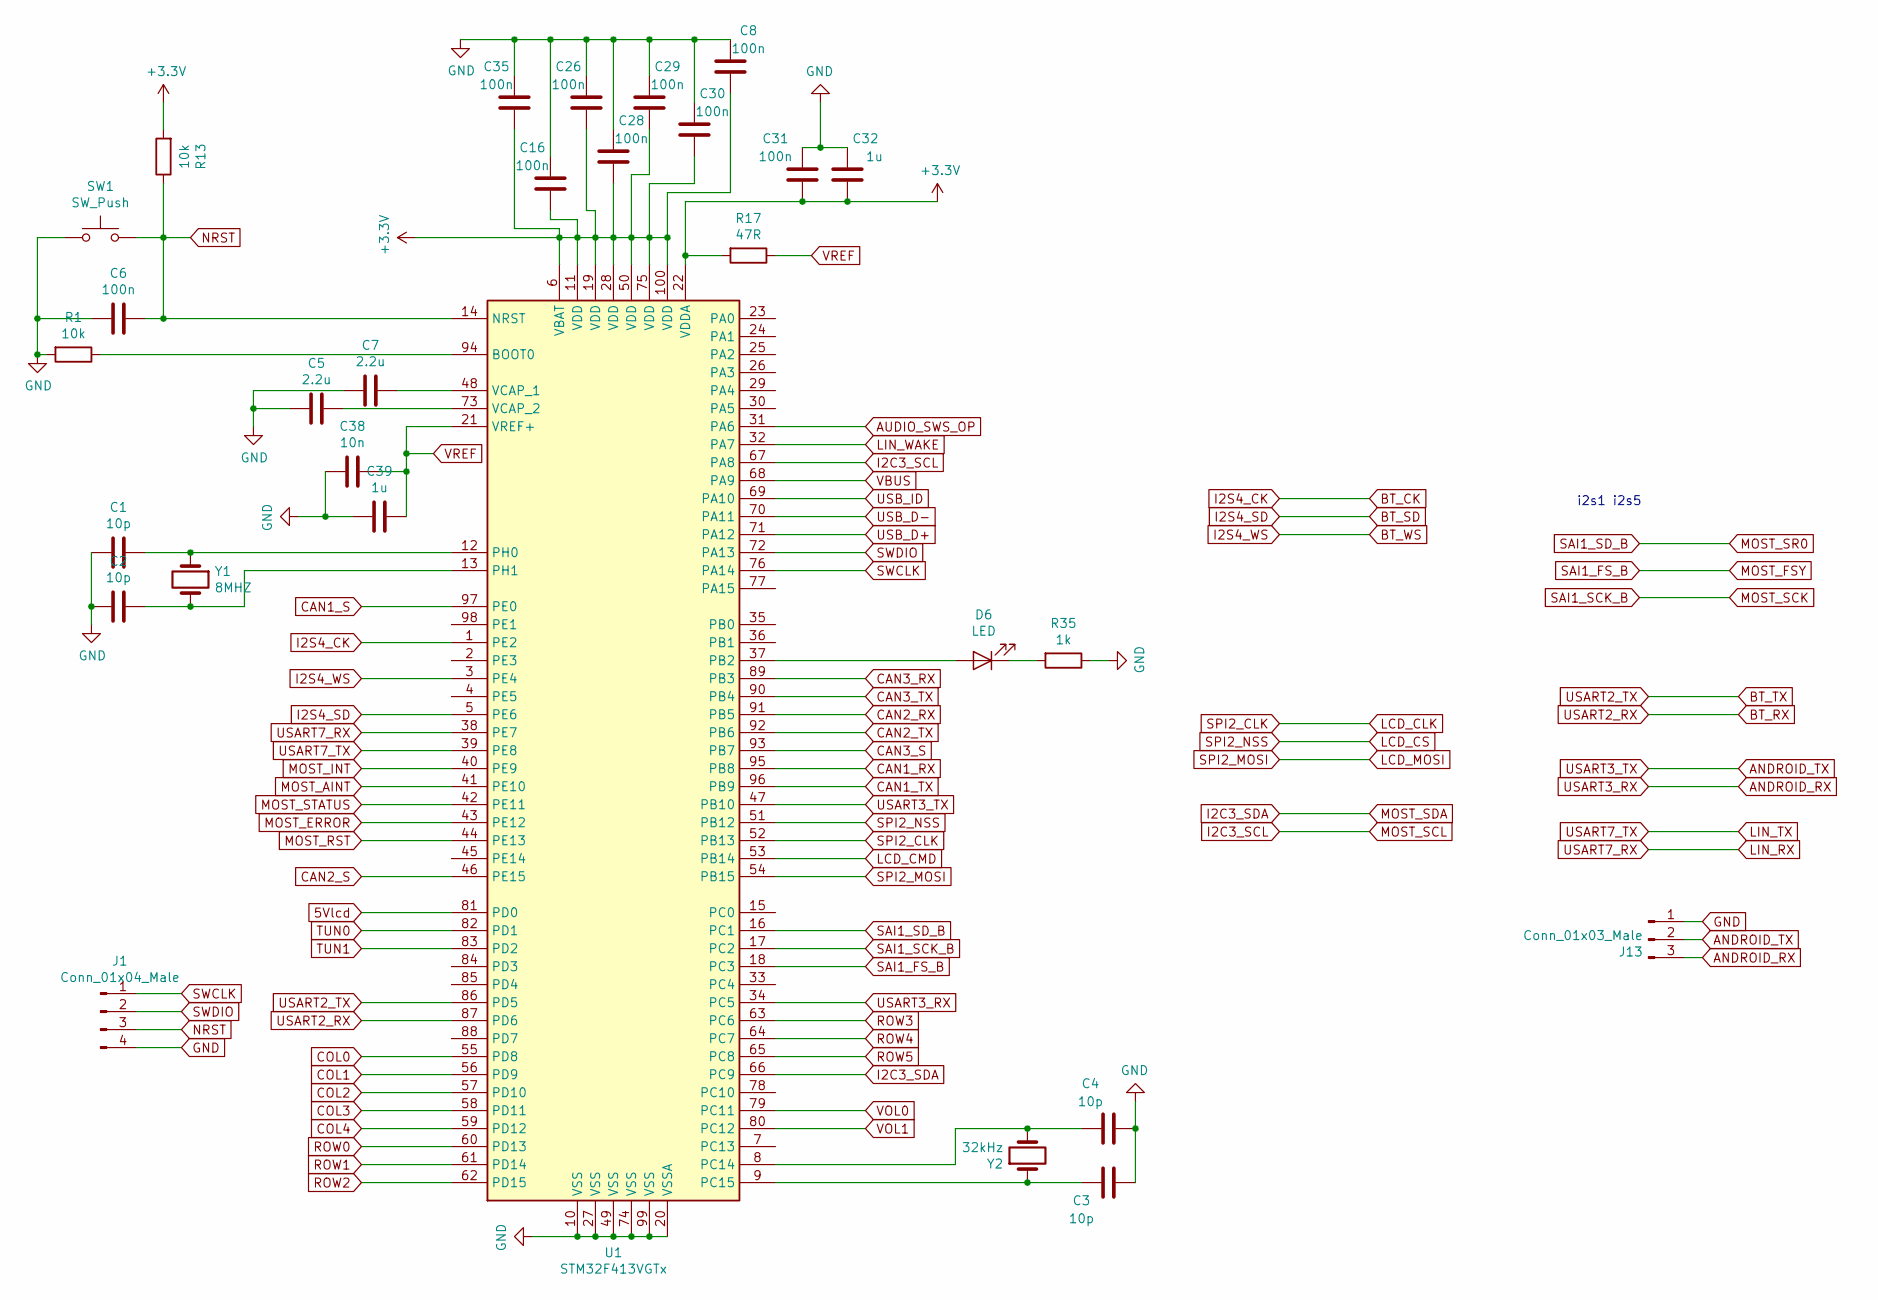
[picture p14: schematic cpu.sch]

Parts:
C1, C2, C3, C4: 10p; C_0805_2012Metric
C5, C7: 2.2u; C_1206_3216Metric
C6, C8, C16, C26, C28, C29, C30, C31, C35: 100n; C_0805_2012Metric
C32, C39: 1u; C_1206_3216Metric
C38: 10n; C_0805_2012Metric
D6: LED; R_0805_2012Metric
J1: Conn_01x04_Male; PinSocket_1x04_P2.54mm_Vertical
J13: Conn_01x03_Male; PinSocket_1x03_P2.54mm_Vertical
R1, R13: 10k; R_0805_2012Metric
R17: 47R; R_0805_2012Metric
R35: 1k; R_0805_2012Metric
SW1: SW_Push; SW_Push_1P1T_NO_6x6mm_H9.5mm
U1: STM32F413VGTx; LQFP-100_14x14mm_P0.5mm
Y1: 8MHZ; Crystal_HC49-U_Vertical
Y2: 32kHz; Crystal_C26-LF_D2.1mm_L6.5mm_Vertical

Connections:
5Vlcd: U1.81 (PD0); also elsewhere on the board
+3V3: C8.1, C16.1, C26.1, C28.1, C29.1, C30.1, C31.1, C32.1, C35.1, R13.2, R17.2, U1.6 (VBAT), U1.11 (VDD), U1.19 (VDD), U1.22 (VDDA), U1.28 (VDD), U1.50 (VDD), U1.75 (VDD), U1.100 (VDD); also elsewhere on the board
ANDROID_RX: J13.3, U1.34 (PC5)
ANDROID_TX: J13.2, U1.47 (PB10)
AUDIO_SWS_OP: U1.31 (PA6); also elsewhere on the board
BT_CK: U1.1 (PE2); also elsewhere on the board
BT_RX: U1.87 (PD6); also elsewhere on the board
BT_SD: U1.5 (PE6); also elsewhere on the board
BT_TX: U1.86 (PD5); also elsewhere on the board
BT_WS: U1.3 (PE4); also elsewhere on the board
CAN1_RX: U1.95 (PB8); also elsewhere on the board
CAN1_S: U1.97 (PE0); also elsewhere on the board
CAN1_TX: U1.96 (PB9); also elsewhere on the board
CAN2_RX: U1.91 (PB5); also elsewhere on the board
CAN2_S: U1.46 (PE15); also elsewhere on the board
CAN2_TX: U1.92 (PB6); also elsewhere on the board
CAN3_RX: U1.89 (PB3); also elsewhere on the board
CAN3_S: U1.93 (PB7); also elsewhere on the board
CAN3_TX: U1.90 (PB4); also elsewhere on the board
COL0: U1.55 (PD8); also elsewhere on the board
COL1: U1.56 (PD9); also elsewhere on the board
COL2: U1.57 (PD10); also elsewhere on the board
COL3: U1.58 (PD11); also elsewhere on the board
COL4: U1.59 (PD12); also elsewhere on the board
GND: C1.2, C2.2, C3.2, C4.2, C5.2, C6.2, C7.2, C8.2, C16.2, C26.2, C28.2, C29.2, C30.2, C31.2, C32.2, C35.2, C38.2, C39.2, J1.4, J13.1, R1.2, R35.1, SW1.1, U1.10 (VSS), U1.20 (VSSA), U1.27 (VSS), U1.49 (VSS), U1.74 (VSS), U1.99 (VSS); also elsewhere on the board
I2C1_SCL: U1.67 (PA8); also elsewhere on the board
I2C1_SDA: U1.66 (PC9); also elsewhere on the board
LCD_CLK: U1.52 (PB13); also elsewhere on the board
LCD_CMD: U1.53 (PB14); also elsewhere on the board
LCD_CS: U1.51 (PB12); also elsewhere on the board
LCD_MOSI: U1.54 (PB15); also elsewhere on the board
LIN_RX: U1.38 (PE7); also elsewhere on the board
LIN_TX: U1.39 (PE8); also elsewhere on the board
LIN_WAKE: U1.32 (PA7); also elsewhere on the board
MOST_AINT: U1.41 (PE10); also elsewhere on the board
MOST_ERROR: U1.43 (PE12); also elsewhere on the board
MOST_FSY: U1.18 (PC3); also elsewhere on the board
MOST_INT: U1.40 (PE9); also elsewhere on the board
MOST_RST: U1.44 (PE13); also elsewhere on the board
MOST_SCK: U1.17 (PC2); also elsewhere on the board
MOST_SR0: U1.16 (PC1); also elsewhere on the board
MOST_STATUS: U1.42 (PE11); also elsewhere on the board
NRST: C6.1, J1.3, R13.1, SW1.2, U1.14 (NRST)
unnamed: C1.1, U1.12 (PH0), Y1.1
unnamed: C2.1, U1.13 (PH1), Y1.2
unnamed: C3.1, U1.9 (PC15), Y2.1
unnamed: C4.1, U1.8 (PC14), Y2.2
unnamed: C5.1, U1.73 (VCAP_2)
unnamed: C7.1, U1.48 (VCAP_1)
unnamed: D6.1 (K), R35.2
unnamed: D6.2 (A), U1.37 (PB2)
unnamed: R1.1, U1.94 (BOOT0)
ROW0: U1.60 (PD13); also elsewhere on the board
ROW1: U1.61 (PD14); also elsewhere on the board
ROW2: U1.62 (PD15); also elsewhere on the board
ROW3: U1.63 (PC6); also elsewhere on the board
ROW4: U1.64 (PC7); also elsewhere on the board
ROW5: U1.65 (PC8); also elsewhere on the board
SWCLK: J1.1, U1.76 (PA14)
SWDIO: J1.2, U1.72 (PA13)
TUN0: U1.82 (PD1); also elsewhere on the board
TUN1: U1.83 (PD2); also elsewhere on the board
USB_D+: U1.71 (PA12); also elsewhere on the board
USB_D-: U1.70 (PA11); also elsewhere on the board
USB_ID: U1.69 (PA10); also elsewhere on the board
VBUS: U1.68 (PA9); also elsewhere on the board
VOL0: U1.79 (PC11); also elsewhere on the board
VOL1: U1.80 (PC12); also elsewhere on the board
VREF: C38.1, C39.1, R17.1, U1.21 (VREF+)

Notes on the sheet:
i2s1 i2s5

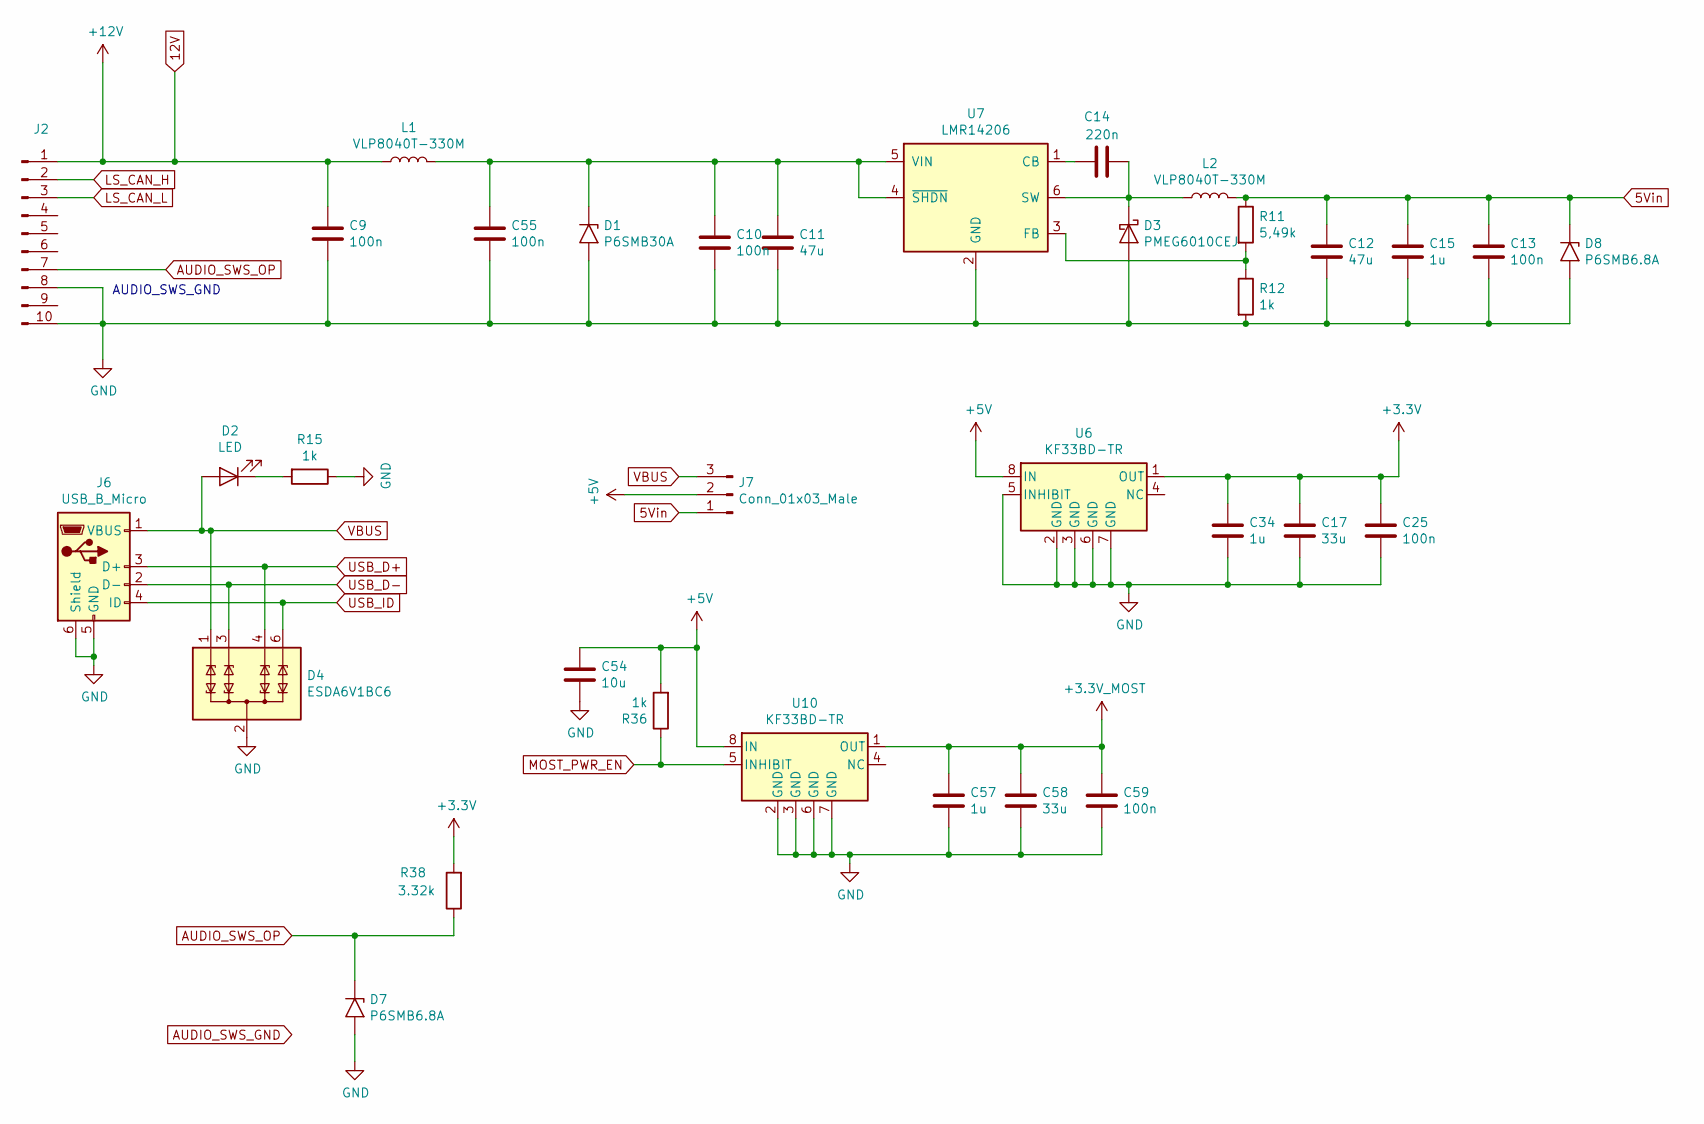
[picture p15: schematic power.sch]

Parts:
C9, C10, C13, C25, C55, C59: 100n; C_0805_2012Metric
C11, C12: 47u; C_1206_3216Metric
C14: 220n; C_0805_2012Metric
C15, C34, C57: 1u; C_1206_3216Metric
C17, C58: 33u; C_1206_3216Metric
C54: 10u; C_1206_3216Metric
D1: P6SMB30A; D_SMB
D2: LED; R_0805_2012Metric
D3: PMEG6010CEJ; D_SOD-323
D4: ESDA6V1BC6; SOT-23-6
D7, D8: P6SMB6.8A; D_SMB
J2: Conn_01x10_Male; IL-AG5-10P-S3L2
J6: USB_B_Micro; USB_Micro-B_Molex-105133-0031
J7: Conn_01x03_Male; PinSocket_1x03_P2.54mm_Vertical
L1, L2: VLP8040T-330M; L_TDK_VLP8040
R11: 5,49k; R_0805_2012Metric
R12, R15, R36: 1k; R_0805_2012Metric
R38: 3.32k; R_0805_2012Metric
U6, U10: KF33BD-TR; SO-8_5.3x6.2mm_P1.27mm
U7: LMR14206; SOT-23-6

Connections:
5Vin: C12.1, C13.1, C15.1, D8.1 (A1), J7.1, L2.2, R11.1
12V: C9.1, J2.1, L1.1; also elsewhere on the board
+3.3_MOST: C57.1, C58.1, C59.1, U10.1 (OUT); also elsewhere on the board
+3V3: C17.1, C25.1, C34.1, R38.2, U6.1 (OUT); also elsewhere on the board
+5V: C54.1, J7.2, R36.2, U6.8 (IN), U10.8 (IN); also elsewhere on the board
AUDIO_SWS_OP: D7.1 (A1), J2.7, R38.1; also elsewhere on the board
GND: C9.2, C10.2, C11.2, C12.2, C13.2, C15.2, C17.2, C25.2, C34.2, C54.2, C55.2, C57.2, C58.2, C59.2, D1.2 (A2), D3.2 (A), D4.2 (COM), D4.5 (COM), D7.2 (A2), D8.2 (A2), J2.8, J2.10, J6.5 (GND), J6.6 (Shield), R12.2, R15.1, U6.2 (GND), U6.3 (GND), U6.5 (INHIBIT), U6.6 (GND), U6.7 (GND), U7.2 (GND), U10.2 (GND), U10.3 (GND), U10.6 (GND), U10.7 (GND); also elsewhere on the board
LS_CAN_H: J2.2; also elsewhere on the board
LS_CAN_L: J2.3; also elsewhere on the board
MOST_PWR_EN: R36.1, U10.5 (INHIBIT)
unnamed: C10.1, C11.1, C55.1, D1.1 (A1), L1.2, U7.4 (~SHDN), U7.5 (VIN)
unnamed: C14.1, U7.1 (CB)
unnamed: C14.2, D3.1 (K), L2.1, U7.6 (SW)
unnamed: D2.1 (K), R15.2
unnamed: R11.2, R12.1, U7.3 (FB)
USB_D+: D4.4 (TVS3), J6.3 (D+); also elsewhere on the board
USB_D-: D4.3 (TVS2), J6.2 (D-); also elsewhere on the board
USB_ID: D4.6 (TVS4), J6.4 (ID); also elsewhere on the board
VBUS: D2.2 (A), D4.1 (TVS1), J6.1 (VBUS), J7.3; also elsewhere on the board

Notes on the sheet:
AUDIO_SWS_GND

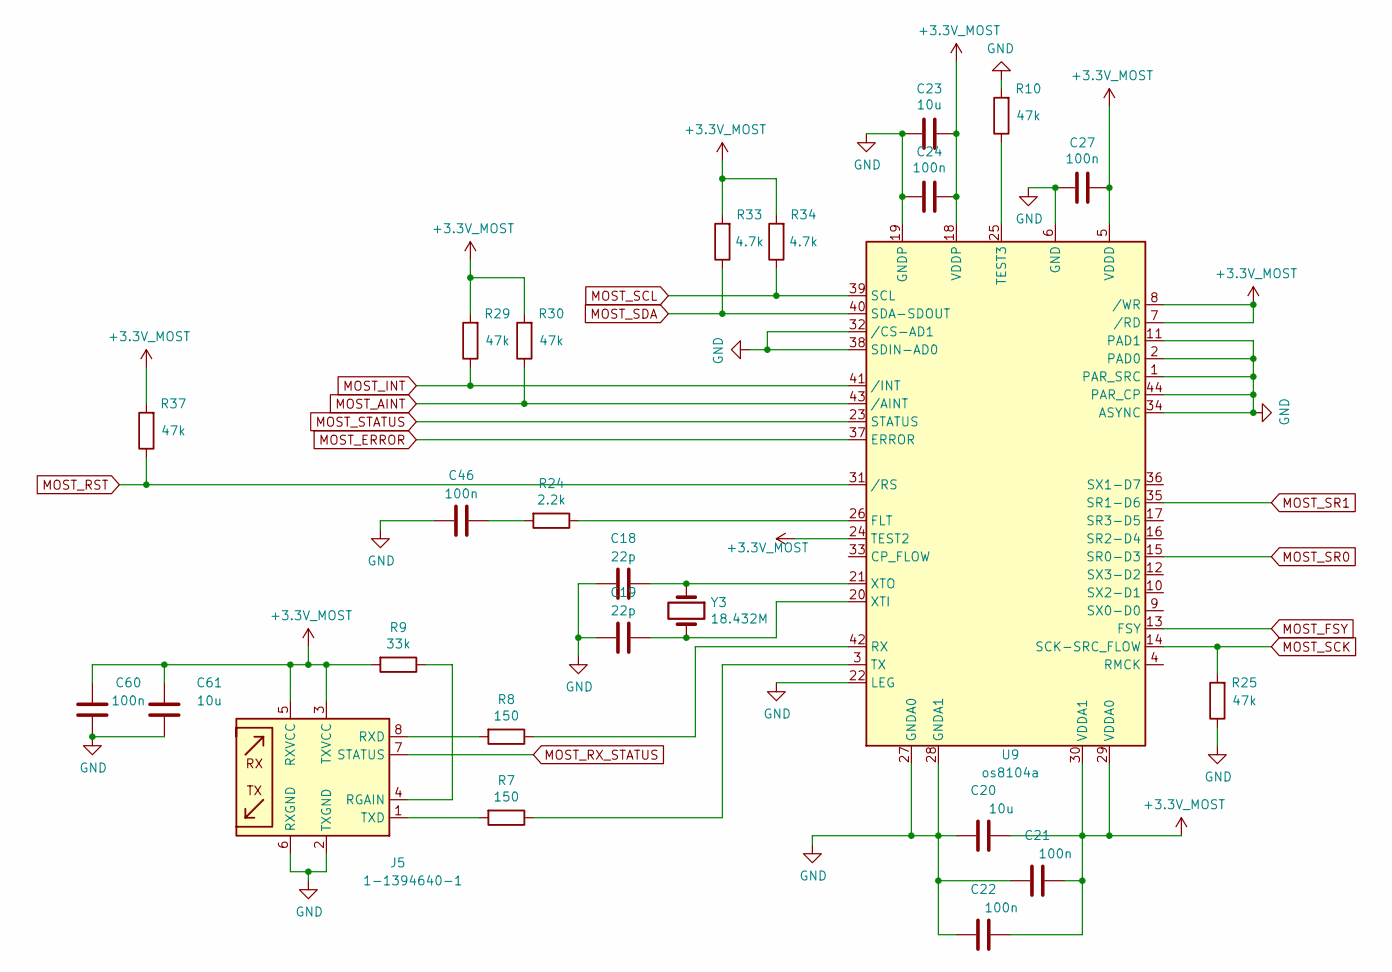
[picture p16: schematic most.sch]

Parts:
C18, C19: 22p; C_0805_2012Metric
C20, C23, C61: 10u; C_1206_3216Metric
C21, C22, C24, C27, C46, C60: 100n; C_0805_2012Metric
J5: 1-1394640-1; TYCO_1_1394640_1
R7, R8: 150; R_0805_2012Metric
R9: 33k; R_0805_2012Metric
R10, R25, R29, R30, R37: 47k; R_0805_2012Metric
R24: 2.2k; R_0805_2012Metric
R33, R34: 4.7k; R_0805_2012Metric
U9: os8104a; LQFP-44_10x10mm_P0.8mm
Y3: 18.432M; Crystal_HC49-U_Vertical

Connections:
+3.3_MOST: C20.1, C21.1, C22.1, C23.1, C24.1, C27.1, C60.2, C61.2, J5.3 (TXVCC), J5.5 (RXVCC), R9.2, R29.2, R30.2, R33.2, R34.2, R37.2, U9.5 (VDDD), U9.7 (/RD), U9.8 (/WR), U9.18 (VDDP), U9.24 (TEST2), U9.29 (VDDA0), U9.30 (VDDA1); also elsewhere on the board
GND: C18.2, C19.2, C20.2, C21.2, C22.2, C23.2, C24.2, C27.2, C46.2, C60.1, C61.1, J5.2 (TXGND), J5.6 (RXGND), R10.2, R25.1, U9.1 (PAR_SRC), U9.2 (PAD0), U9.6 (GND), U9.11 (PAD1), U9.19 (GNDP), U9.22 (LEG), U9.27 (GNDA0), U9.28 (GNDA1), U9.32 (/CS-AD1), U9.34 (ASYNC), U9.38 (SDIN-AD0), U9.44 (PAR_CP); also elsewhere on the board
I2C1_SCL: R34.1, U9.39 (SCL); also elsewhere on the board
I2C1_SDA: R33.1, U9.40 (SDA-SDOUT); also elsewhere on the board
MOST_AINT: R30.1, U9.43 (/AINT); also elsewhere on the board
MOST_ERROR: U9.37 (ERROR); also elsewhere on the board
MOST_FSY: U9.13 (FSY); also elsewhere on the board
MOST_INT: R29.1, U9.41 (/INT); also elsewhere on the board
MOST_RST: R37.1, U9.31 (/RS); also elsewhere on the board
MOST_RX_STATUS: J5.7 (STATUS)
MOST_SCK: R25.2, U9.14 (SCK-SRC_FLOW); also elsewhere on the board
MOST_SR0: U9.15 (SR0-D3); also elsewhere on the board
MOST_SR1: U9.35 (SR1-D6)
MOST_STATUS: U9.23 (STATUS); also elsewhere on the board
unnamed: C18.1, U9.21 (XTO), Y3.1
unnamed: C19.1, U9.20 (XTI), Y3.2
unnamed: C46.1, R24.2
unnamed: J5.1 (TXD), R7.2
unnamed: J5.4 (RGAIN), R9.1
unnamed: J5.8 (RXD), R8.2
unnamed: R7.1, U9.3 (TX)
unnamed: R8.1, U9.42 (RX)
unnamed: R10.1, U9.25 (TEST3)
unnamed: R24.1, U9.26 (FLT)

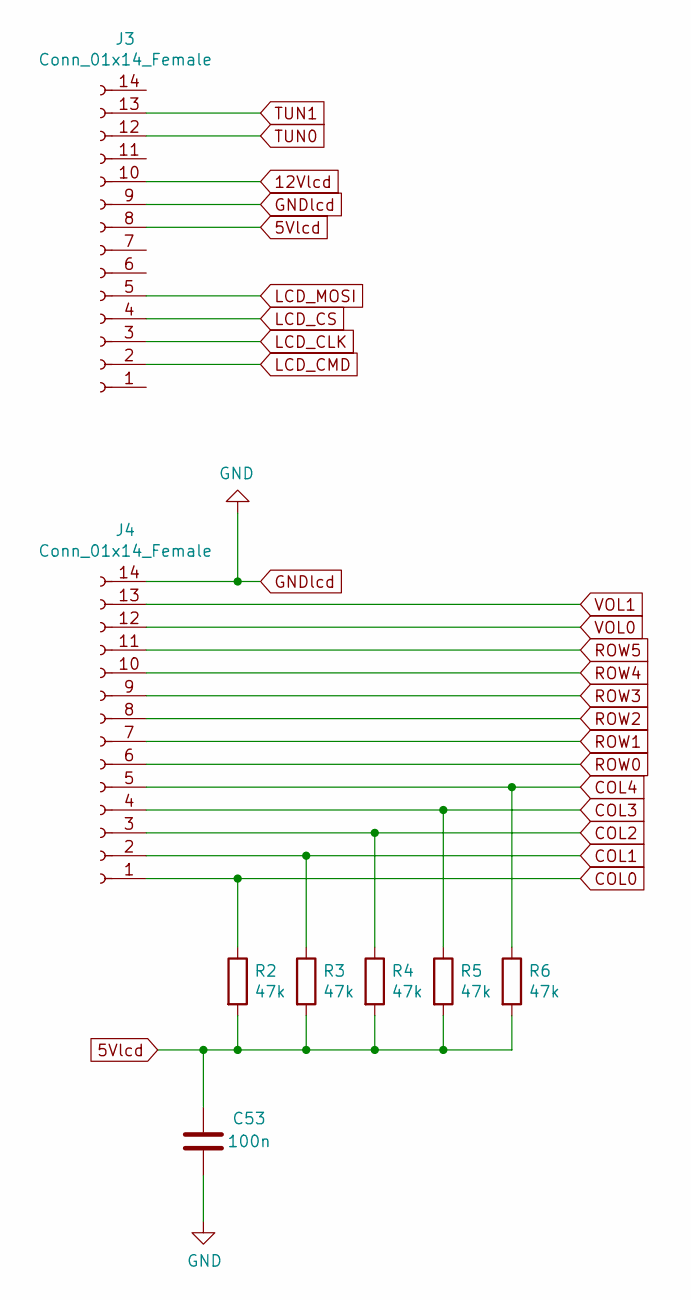
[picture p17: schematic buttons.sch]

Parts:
C53: 100n; C_0805_2012Metric
J3, J4: Conn_01x14_Female; 1x14-2.00mm
R2, R3, R4, R5, R6: 47k; R_0805_2012Metric

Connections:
5Vlcd: C53.2, J3.8, R2.2, R3.2, R4.2, R5.2, R6.2; also elsewhere on the board
12Vlcd: J3.10
COL0: J4.1, R2.1; also elsewhere on the board
COL1: J4.2, R3.1; also elsewhere on the board
COL2: J4.3, R4.1; also elsewhere on the board
COL3: J4.4, R5.1; also elsewhere on the board
COL4: J4.5, R6.1; also elsewhere on the board
GND: C53.1, J3.9, J4.14; also elsewhere on the board
LCD_CLK: J3.3; also elsewhere on the board
LCD_CMD: J3.2; also elsewhere on the board
LCD_CS: J3.4; also elsewhere on the board
LCD_MOSI: J3.5; also elsewhere on the board
ROW0: J4.6; also elsewhere on the board
ROW1: J4.7; also elsewhere on the board
ROW2: J4.8; also elsewhere on the board
ROW3: J4.9; also elsewhere on the board
ROW4: J4.10; also elsewhere on the board
ROW5: J4.11; also elsewhere on the board
TUN0: J3.12; also elsewhere on the board
TUN1: J3.13; also elsewhere on the board
VOL0: J4.12; also elsewhere on the board
VOL1: J4.13; also elsewhere on the board

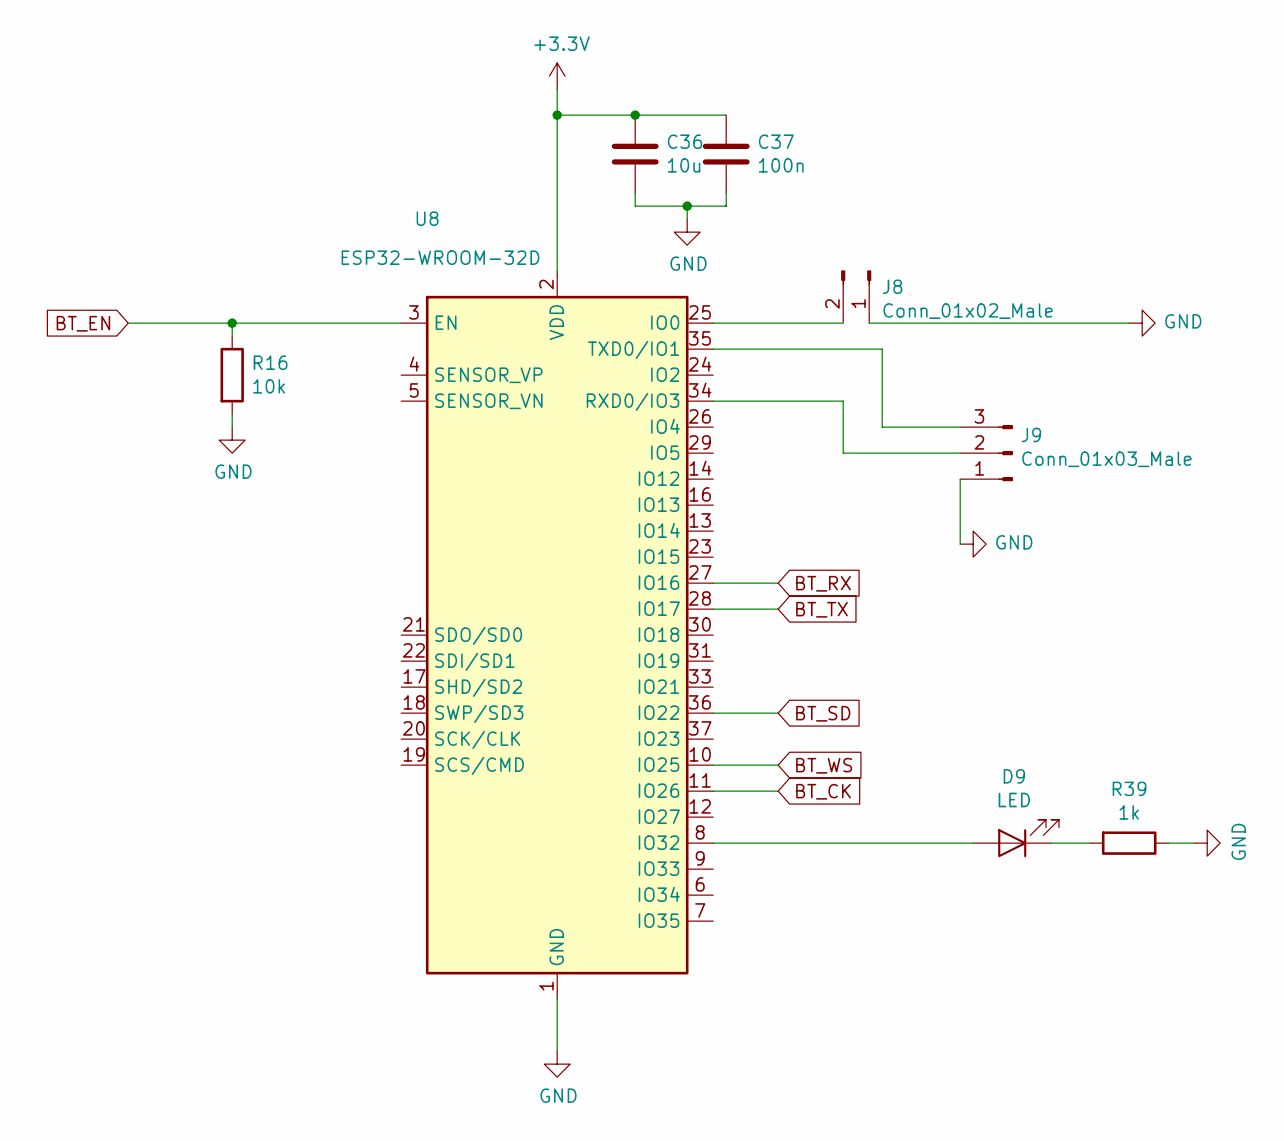
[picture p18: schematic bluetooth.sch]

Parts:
C36: 10u; C_1206_3216Metric
C37: 100n; C_0805_2012Metric
D9: LED; R_0805_2012Metric
J8: Conn_01x02_Male; PinSocket_1x02_P2.54mm_Vertical
J9: Conn_01x03_Male; PinSocket_1x03_P2.54mm_Vertical
R16: 10k; R_0805_2012Metric
R39: 1k; R_0805_2012Metric
U8: ESP32-WROOM-32D; ESP32-WROOM-32

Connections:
+3V3: C36.1, C37.1, U8.2 (VDD); also elsewhere on the board
BT_CK: U8.11 (IO26); also elsewhere on the board
BT_EN: R16.1, U8.3 (EN)
BT_RX: U8.27 (IO16); also elsewhere on the board
BT_SD: U8.36 (IO22); also elsewhere on the board
BT_TX: U8.28 (IO17); also elsewhere on the board
BT_WS: U8.10 (IO25); also elsewhere on the board
GND: C36.2, C37.2, J8.1, J9.1, R16.2, R39.1, U8.1 (GND), U8.15 (GND), U8.38 (GND); also elsewhere on the board
unnamed: D9.1 (K), R39.2
unnamed: D9.2 (A), U8.8 (IO32)
unnamed: J8.2, U8.25 (IO0)
unnamed: J9.2, U8.34 (RXD0/IO3)
unnamed: J9.3, U8.35 (TXD0/IO1)


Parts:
C40, C41, C49: 4.7u; C_1206_3216Metric
C42, C43, C44, C45, C47, C48, C50, C51, C52: 100n; C_0805_2012Metric
C56: 1n; C_0805_2012Metric
D5: DIODE; R_0805_2012Metric
J10: Conn_01x04_Male; PinSocket_1x04_P2.54mm_Vertical
J11, J12: Conn_01x03_Male; PinSocket_1x03_P2.54mm_Vertical
Q1: IRLML2803; SOT-23
R14: 4.7k; R_0805_2012Metric
R18, R19, R26, R31: 10k; R_0805_2012Metric
R20, R21, R22, R23, R27, R28: 60R; R_0805_2012Metric
R32: 1k; R_0805_2012Metric
U2, U3, U4: TJA1051T-3; SOIC-8_3.9x4.9mm_P1.27mm
U5: TJA1021T; SOIC-8_3.9x4.9mm_P1.27mm

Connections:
12V: J10.1, J12.3, R31.1, U5.7 (VBAT); also elsewhere on the board
+3V3: C47.2, C48.2, C52.2, R18.1, R19.1, R26.1, U2.5 (VIO), U3.5 (VIO), U4.5 (VIO); also elsewhere on the board
+5V: C40.2, C41.2, C42.2, C43.2, C49.2, C50.2, U2.3 (VCC), U3.3 (VCC), U4.3 (VCC); also elsewhere on the board
CAN1_RX: U4.4 (RXD); also elsewhere on the board
CAN1_S: R19.2, U4.8 (S); also elsewhere on the board
CAN1_TX: U4.1 (TXD); also elsewhere on the board
CAN2_RX: U3.4 (RXD); also elsewhere on the board
CAN2_S: R18.2, U3.8 (S); also elsewhere on the board
CAN2_TX: U3.1 (TXD); also elsewhere on the board
CAN3_RX: U2.4 (RXD); also elsewhere on the board
CAN3_S: R26.2, U2.8 (S); also elsewhere on the board
CAN3_TX: U2.1 (TXD); also elsewhere on the board
CAN_H: J10.2, R28.2, U2.7 (CANH)
CAN_L: J10.3, R27.2, U2.6 (CANL)
GND: C40.1, C41.1, C42.1, C43.1, C44.1, C45.1, C47.1, C48.1, C49.1, C50.1, C51.1, C52.1, C56.1, J10.4, J11.1, J12.1, Q1.2 (S), R14.1, U2.2 (GND), U3.2 (GND), U4.2 (GND), U5.5 (GND); also elsewhere on the board
HS_CAN_H: J11.3, R22.2, U3.7 (CANH)
HS_CAN_L: J11.2, R20.2, U3.6 (CANL)
LIN: C56.2, J12.2, R32.1, U5.6 (LIN)
LIN_RX: U5.1 (RXD); also elsewhere on the board
LIN_SLP: U5.2 (~SLP~)
LIN_TX: U5.4 (TXD); also elsewhere on the board
LIN_WAKE: Q1.1 (G), R14.2; also elsewhere on the board
LS_CAN_H: R23.2, U4.7 (CANH); also elsewhere on the board
LS_CAN_L: R21.2, U4.6 (CANL); also elsewhere on the board
unnamed: C44.2, R20.1, R22.1
unnamed: C45.2, R21.1, R23.1
unnamed: C51.2, R27.1, R28.1
unnamed: D5.1 (K), U5.8 (INH)
unnamed: D5.2 (A), R32.2
unnamed: Q1.3 (D), R31.2, U5.3 (~WAKE~)


Board: 2 copper layers, 100.0 x 100.0 mm, 138 parts (0 on the bottom side), 108 nets.

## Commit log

2019-08-29 added hardware files
    [bluetooth.sch, buttons.sch, can.sch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]
2019-08-29 added pcb image
2020-04-05 added hardware files v2
    [buttons.sch, can.sch, cpu.sch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]
2020-10-16 added hardware files v3
    [buttons.sch, can.sch, cpu.sch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]
2020-10-16 added hardware files for adapter-lr2
    [adapter-B_Cu.gbr, adapter-B_Mask.gbr, adapter-B_Paste.gbr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]
2020-10-16 added schematic file in pdf format
2020-10-27 added a photo of the boardv3
